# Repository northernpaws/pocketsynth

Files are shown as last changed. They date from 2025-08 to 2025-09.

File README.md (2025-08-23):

# Pocket Synth

[Online Board & Schematic View](https://kicanvas.org/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)

This repository contains my project for an STM32H7-based sequencer, synthesizer, and sampler, all in a small phone-sized pocketable form factor. 

  * 480 MHz Arm® Cortex®-M7 32-bit Processor (`STM32H743ZIT6`)
    * Floating-point unit
    * DSP instructions
    * High-speed memory controller
    * Quad SPI interface for flash
    * High-speed USB host and device mode
    * Several SAI audio blocks
  * 2.4" 240x320 TFT IPS Display (`ER-TFT024IPS-3`)
    * Capacitive touch
  * 24 bit Audio Codec (`NAU88C22YG`)
    * DAC: 94dB SNR and -84dB THD (“A” weighted)
    * ADC: 90dB SNR and -80dB THD (“A” weighted)
    * Integrated BTL speaker driver: 1W into 8Ω
    * Integrated head-phone driver: 40mW into 16Ω
  * Optional Bluetooth Classic and BLE Audio Source (`FSC-BT6038`)
    * Wirelessly connect Bluethooth headphones and speakers
    * Supports various high-fedality audio protocols
    * Note: Audio transmitter does not support other BLE protocols, such as MIDI
  * Optional Wifi and BLE capabilities (`ESP32-C3-MINI-1`)
    * Wifi sample management and transfer
    * BLE MIDI
  * Interal speaker
  * Internal microphone
  * SDRAM for sample pool and audio processing
    * Part allocated to in-memory sample pool for project
    * Part allocated to audio effects processing
    * Variable sizes in similar footprint available, up to 512Mbit:
        * 16bit * 48000Hz = 768,000b/s = 0.768Mb/s
        * 128Mb / 0.768Mb/s = 166.66 seconds of mono audio (`IS42S16800J-7TL`)
        * 256Mb / 0.768Mb/s = 333.33 seconds of mono audio (`IS42S16160J-7TLI`)
        * 512Mb / 0.768Mb/s = 666.66 seconds of mono audio (`IS42S16320F-7TLI`)
  * Micro SD Card
    * Saving and loading projects
      * Transfer and back up projects to a computer
    * Saving and loading samples
      * Load samples from a computer
      * Save samples recorded on the device
  * 3.3v NOR Flash (`MT25QUxxxxxx1xW7` 256M/128M/64M)
    * Stores device settings
    * Small storage space for projects and samples without SD card
    * Provides storage for cross-SD card samples
  * USB-C
    * USB-PD fast charging
    * Possible future audio interface mode
  * MIDI in/out via TRS minijack
  * 16 Multi-Purpose primary keys
    * Hot-swappable Kalih Choc keyswitches (V1 and V2 compatible)
    * RGB LEDs for state indicators
  * Accelerometer and Gyroscope (`LSM6DS3`)
    * Can be used as sequencer parameters
    * Can be recorded for automation inputs
    * Used for auto sleep/wake
  * USB-PD Battery Charge Controller (`MAX77789` or `MAX77757`)
    * 3A fast-charge current
    * 13.4V input voltage
    * Detection for legacy SDP, DCP, and CDP chargers
  * Two-Button Smart Reset (`STM6510`)
    * Hold two input buttons to power off the device if it freezes and power gets latched on

## Step Sequencer

The step sequencer on the device is modeled after popular semantics used by hardware sequencers, such as the Elektron Digitone and Digitakt, OP-1, OP-Z, Pocket Operators, Woovebox, etc.

> The hard requirements of the step sequencer and audio engine are not defined yet because they are under active development.

  * As many projects as the SD card or internal memory can store
    * 128 Patterns (TBD)
      * 8-16 Audio or MIDI tracks per pattern (TBD)
    * 8-24 Songs (arrangements of patterns) (TBD)
  * 8-16 voice polyphony (TBD)
    * 2-3 LFO per voice (TBD)

## Audio

The primary audio engine chain runs at 16bit 44.1Khz, but supports stereo audio effects. 16 bit audio was selected as it had suitable depth without being too large for a small embedded device to reasonably process. 44.1Khz also has a good frequency range, and has been the standard for CDs and many music streaming platforms for a long time.

### Sampling

The sampling engine runs 16bit 44.1Khz and saves and loads samples in single-channel mono.

Samples recoded from the internal or external mic are sampled at 24 bits into the device's SDRAM to provide a decent noise floor, and then filtered and downsampled to 16 bits for saving after they've been edited by the user.

The 16bit @ 44.1Khz sampling parameters provdes a good balance between audio quality, and reasonable utilization of the SDRAM without needing extremely large and expensive SDRAM chips:

```
16bit * 48000Hz = 768,000b/s = 0.768Mb/s
128Mb / 0.768Mb/s = 166.66 seconds of mono audio
256Mb / 0.768Mb/s = 333.33 seconds of mono audio
512Mb / 0.768Mb/s = 666.66 seconds of mono audio
```

> Note that some of the space calculated above (actual amount will be configurable) is allocated to the audio effects processing chain, i.e. for reverb and delay. 

## Attribution

### 3D Models

Majority of 3D models for PCB components are from their respective manufactures, with the exception of:

  - https://grabcad.com/library/kailh-low-profile-mechanical-keyboard-switch-1
  - https://grabcad.com/library/kailh-low-profile-keycaps-1
  - https://cad.grabcad.com/library/sk6812mini-e-led-1

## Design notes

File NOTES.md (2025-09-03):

## For next revision (0.2)

  * Remove volume + power knob to make room for 2x MIDI ports
  * make MIDI in/out ports multi-functional, supporting CV and sync signals

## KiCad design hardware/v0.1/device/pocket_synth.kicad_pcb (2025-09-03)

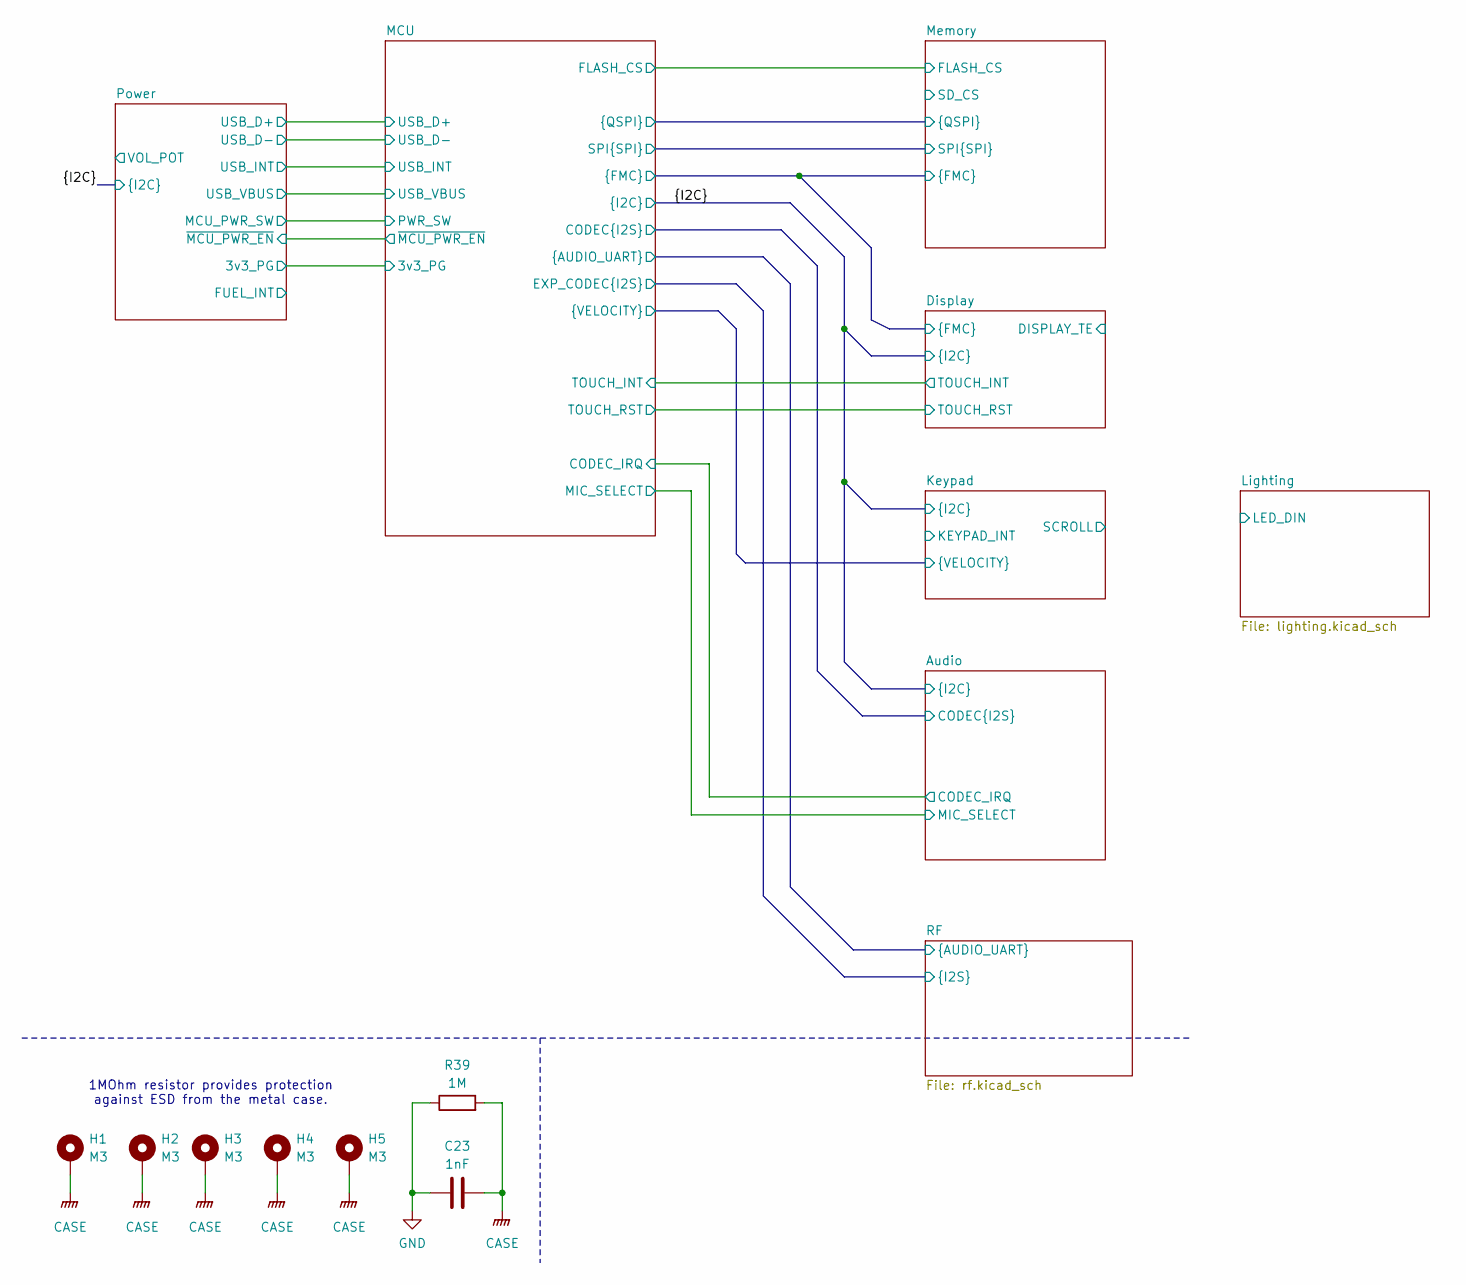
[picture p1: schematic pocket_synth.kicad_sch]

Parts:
C23: 1nF
H1, H2, H3, H4, H5: M3; MountingHole_3.2mm_M3_DIN965_Pad
R39: 1M

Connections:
CASE: C23.2, H1.1, H2.1, H3.1, H4.1, H5.1, R39.2
unnamed: C23.1, R39.1

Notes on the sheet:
1MOhm resistor provides protection against ESD from the metal case.

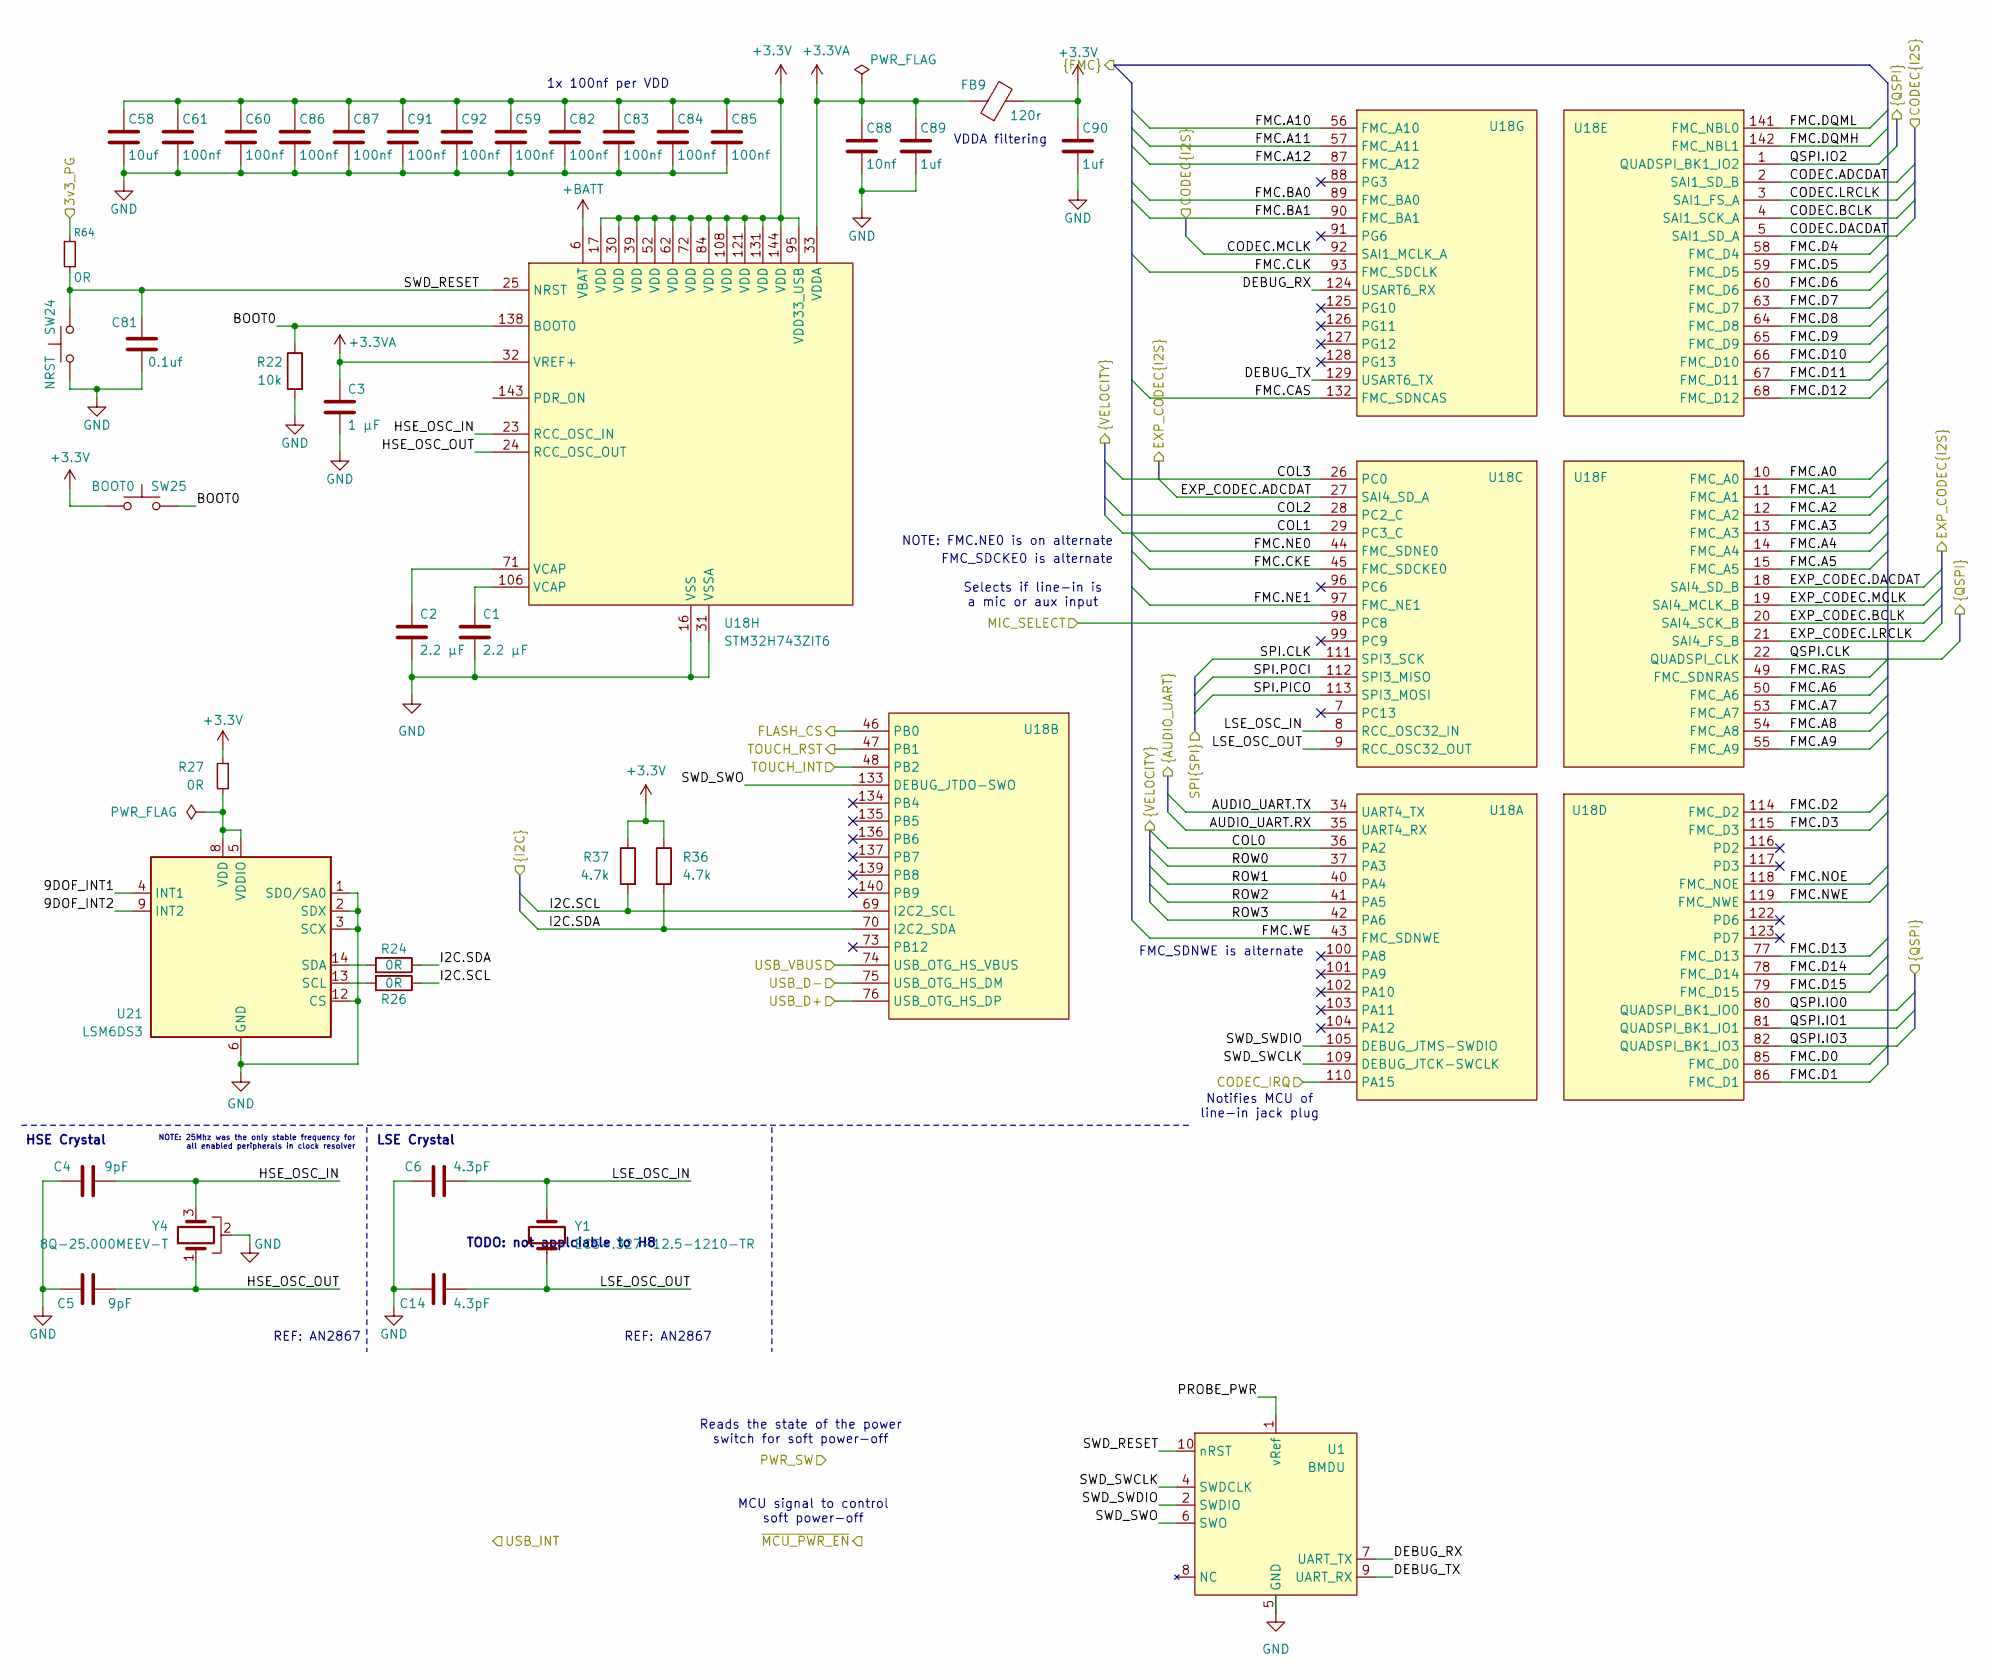
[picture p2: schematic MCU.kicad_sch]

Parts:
C1, C2: 2.2 µF; C_0402_1005Metric
C3: 1 µF; C_0402_1005Metric
C4, C5: 9pF; C_0402_1005Metric
C6, C14: 4.3pF; C_0402_1005Metric
C58: 10uf; C_0402_1005Metric
C59, C60, C61, C82, C83, C84, C85, C86, C87, C91, C92: 100nf; C_0402_1005Metric
C81: 0.1uf; C_0402_1005Metric
C88: 10nf; C_0402_1005Metric
C89, C90: 1uf; C_0402_1005Metric
FB9: 120r; L_0603_1608Metric
R22: 10k; R_0402_1005Metric
R24, R26, R27, R64: 0R; R_0402_1005Metric
R36, R37: 4.7k; R_0402_1005Metric
SW24: NRST; SW_SPST_B3U-1000P
SW25: BOOT0; SW_SPST_B3U-1000P
U1: BMDU; SAMTEC_FTSH-105-01-F-D-K
U18: STM32H743ZIT6; LQFP-144_20x20mm_P0.5mm; JLC C114408
U21: LSM6DS3; LGA-14_3x2.5mm_P0.5mm_LayoutBorder3x4y
Y1: ECS-.327-12.5-1210-TR; XTAL_ECS-.327-12.5-1210-TR; JLC C435179
Y4: 8Q-25.000MEEV-T; XTAL_8Q-25.000MEEV-T

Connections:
+3.3V: C58.1, C59.1, C60.1, C61.1, C82.1, C83.1, C84.1, C85.1, C86.1, C87.1, C90.1, C91.1, C92.1, FB9.2, R27.1, R36.1, R37.1, SW25.1, U18.17 (VDD), U18.30 (VDD), U18.39 (VDD), U18.52 (VDD), U18.62 (VDD), U18.72 (VDD), U18.84 (VDD), U18.95 (VDD33_USB), U18.108 (VDD), U18.121 (VDD), U18.131 (VDD), U18.144 (VDD); also elsewhere on the board
+3.3VA: C3.1, C88.1, C89.1, FB9.1, U18.32 (VREF+), U18.33 (VDDA)
+BATT: U18.6 (VBAT); also elsewhere on the board
/Audio/CODEC.ADCDAT: U18.2 (SAI1_SD_B); also elsewhere on the board
/Audio/CODEC.BCLK: U18.4 (SAI1_SCK_A); also elsewhere on the board
/Audio/CODEC.DACDAT: U18.5 (SAI1_SD_A); also elsewhere on the board
/Audio/CODEC.LRCLK: U18.3 (SAI1_FS_A); also elsewhere on the board
/Audio/CODEC.MCLK: U18.92 (SAI1_MCLK_A); also elsewhere on the board
/Audio/CODEC_IRQ: U18.110 (PA15); also elsewhere on the board
/Audio/MIC_SELECT: U18.98 (PC8); also elsewhere on the board
/Display/FMC.A0: U18.10 (FMC_A0); also elsewhere on the board
/Display/FMC.A1: U18.11 (FMC_A1); also elsewhere on the board
/Display/FMC.A2: U18.12 (FMC_A2); also elsewhere on the board
/Display/FMC.A3: U18.13 (FMC_A3); also elsewhere on the board
/Display/FMC.A4: U18.14 (FMC_A4); also elsewhere on the board
/Display/FMC.A5: U18.15 (FMC_A5); also elsewhere on the board
/Display/FMC.A6: U18.50 (FMC_A6); also elsewhere on the board
/Display/FMC.A7: U18.53 (FMC_A7); also elsewhere on the board
/Display/FMC.A8: U18.54 (FMC_A8); also elsewhere on the board
/Display/FMC.A9: U18.55 (FMC_A9); also elsewhere on the board
/Display/FMC.A10: U18.56 (FMC_A10); also elsewhere on the board
/Display/FMC.A11: U18.57 (FMC_A11); also elsewhere on the board
/Display/FMC.A12: U18.87 (FMC_A12); also elsewhere on the board
/Display/FMC.BA0: U18.89 (FMC_BA0); also elsewhere on the board
/Display/FMC.BA1: U18.90 (FMC_BA1); also elsewhere on the board
/Display/FMC.CAS: U18.132 (FMC_SDNCAS); also elsewhere on the board
/Display/FMC.CKE: U18.45 (FMC_SDCKE0); also elsewhere on the board
/Display/FMC.CLK: U18.93 (FMC_SDCLK); also elsewhere on the board
/Display/FMC.D0: U18.85 (FMC_D0); also elsewhere on the board
/Display/FMC.D1: U18.86 (FMC_D1); also elsewhere on the board
/Display/FMC.D2: U18.114 (FMC_D2); also elsewhere on the board
/Display/FMC.D3: U18.115 (FMC_D3); also elsewhere on the board
/Display/FMC.D4: U18.58 (FMC_D4); also elsewhere on the board
/Display/FMC.D5: U18.59 (FMC_D5); also elsewhere on the board
/Display/FMC.D6: U18.60 (FMC_D6); also elsewhere on the board
/Display/FMC.D7: U18.63 (FMC_D7); also elsewhere on the board
/Display/FMC.D8: U18.64 (FMC_D8); also elsewhere on the board
/Display/FMC.D9: U18.65 (FMC_D9); also elsewhere on the board
/Display/FMC.D10: U18.66 (FMC_D10); also elsewhere on the board
/Display/FMC.D11: U18.67 (FMC_D11); also elsewhere on the board
/Display/FMC.D12: U18.68 (FMC_D12); also elsewhere on the board
/Display/FMC.D13: U18.77 (FMC_D13); also elsewhere on the board
/Display/FMC.D14: U18.78 (FMC_D14); also elsewhere on the board
/Display/FMC.D15: U18.79 (FMC_D15); also elsewhere on the board
/Display/FMC.DQMH: U18.142 (FMC_NBL1); also elsewhere on the board
/Display/FMC.DQML: U18.141 (FMC_NBL0); also elsewhere on the board
/Display/FMC.NE0: U18.44 (FMC_SDNE0); also elsewhere on the board
/Display/FMC.NE1: U18.97 (FMC_NE1); also elsewhere on the board
/Display/FMC.NOE: U18.118 (FMC_NOE); also elsewhere on the board
/Display/FMC.NWE: U18.119 (FMC_NWE); also elsewhere on the board
/Display/FMC.RAS: U18.49 (FMC_SDNRAS); also elsewhere on the board
/Display/FMC.WE: U18.43 (FMC_SDNWE); also elsewhere on the board
/Display/TOUCH_INT: U18.48 (PB2); also elsewhere on the board
/Display/TOUCH_RST: U18.47 (PB1); also elsewhere on the board
/I2C.SCL: R26.1, R37.2, U18.69 (I2C2_SCL); also elsewhere on the board
/I2C.SDA: R24.1, R36.2, U18.70 (I2C2_SDA); also elsewhere on the board
/Keypad/COL0: U18.36 (PA2); also elsewhere on the board
/Keypad/COL1: U18.29 (PC3_C); also elsewhere on the board
/Keypad/COL2: U18.28 (PC2_C); also elsewhere on the board
/Keypad/COL3: U18.26 (PC0); also elsewhere on the board
/Keypad/ROW0: U18.37 (PA3); also elsewhere on the board
/Keypad/ROW1: U18.40 (PA4); also elsewhere on the board
/Keypad/ROW2: U18.41 (PA5); also elsewhere on the board
/Keypad/ROW3: U18.42 (PA6); also elsewhere on the board
/MCU/9DOF_INT1: U21.4 (INT1)
/MCU/9DOF_INT2: U21.9 (INT2)
/MCU/AUDIO_UART.RX: U18.35 (UART4_RX); also elsewhere on the board
/MCU/AUDIO_UART.TX: U18.34 (UART4_TX); also elsewhere on the board
/MCU/BOOT0: R22.1, SW25.2, U18.138 (BOOT0)
/MCU/DEBUG_RX: U1.7 (UART_TX), U18.124 (USART6_RX)
/MCU/DEBUG_TX: U1.9 (UART_RX), U18.129 (USART6_TX)
/MCU/EXP_CODEC.ADCDAT: U18.27 (SAI4_SD_A); also elsewhere on the board
/MCU/EXP_CODEC.BCLK: U18.20 (SAI4_SCK_B); also elsewhere on the board
/MCU/EXP_CODEC.DACDAT: U18.18 (SAI4_SD_B); also elsewhere on the board
/MCU/EXP_CODEC.LRCLK: U18.21 (SAI4_FS_B); also elsewhere on the board
/MCU/EXP_CODEC.MCLK: U18.19 (SAI4_MCLK_B); also elsewhere on the board
/MCU/FLASH_CS: U18.46 (PB0); also elsewhere on the board
/MCU/HSE_OSC_IN: C4.2, U18.23 (RCC_OSC_IN), Y4.3
/MCU/HSE_OSC_OUT: C5.2, U18.24 (RCC_OSC_OUT), Y4.1
/MCU/LSE_OSC_IN: C6.2, U18.8 (RCC_OSC32_IN), Y1.2
/MCU/LSE_OSC_OUT: C14.2, U18.9 (RCC_OSC32_OUT), Y1.1
/MCU/PROBE_PWR: U1.1 (vRef)
/MCU/QSPI.CLK: U18.22 (QUADSPI_CLK); also elsewhere on the board
/MCU/QSPI.IO0: U18.80 (QUADSPI_BK1_IO0); also elsewhere on the board
/MCU/QSPI.IO1: U18.81 (QUADSPI_BK1_IO1); also elsewhere on the board
/MCU/QSPI.IO2: U18.1 (QUADSPI_BK1_IO2); also elsewhere on the board
/MCU/QSPI.IO3: U18.82 (QUADSPI_BK1_IO3); also elsewhere on the board
/MCU/SPI.CLK: U18.111 (SPI3_SCK); also elsewhere on the board
/MCU/SPI.PICO: U18.113 (SPI3_MOSI); also elsewhere on the board
/MCU/SPI.POCI: U18.112 (SPI3_MISO); also elsewhere on the board
/MCU/SWD_RESET: C81.2, R64.2, SW24.2, U1.10 (nRST), U18.25 (NRST)
/MCU/SWD_SWCLK: U1.4 (SWDCLK), U18.109 (DEBUG_JTCK-SWCLK)
/MCU/SWD_SWDIO: U1.2 (SWDIO), U18.105 (DEBUG_JTMS-SWDIO)
/MCU/SWD_SWO: U1.6 (SWO), U18.133 (DEBUG_JTDO-SWO)
/MCU/USB_VBUS: U18.74 (USB_OTG_HS_VBUS)
/Power/3v3_PG: R64.1; also elsewhere on the board
/Power/USB_D+: U18.76 (USB_OTG_HS_DP); also elsewhere on the board
/Power/USB_D-: U18.75 (USB_OTG_HS_DM); also elsewhere on the board
GND: C1.2, C2.2, C3.2, C4.1, C5.1, C6.1, C14.1, C58.2, C59.2, C60.2, C61.2, C81.1, C82.2, C83.2, C84.2, C85.2, C86.2, C87.2, C88.2, C89.2, C90.2, C91.2, C92.2, R22.2, SW24.1, U1.3 (GND), U1.5 (GND), U18.16 (VSS), U18.31 (VSSA), U18.38 (VSS), U18.51 (VSS), U18.61 (VSS), U18.83 (VSS), U18.94 (VSS), U18.107 (VSS), U18.120 (VSS), U18.130 (VSS), U21.1 (SDO/SA0), U21.2 (SDX), U21.3 (SCX), U21.6 (GND), U21.7 (GND), U21.12 (CS), Y4.2; also elsewhere on the board
unnamed: C1.1, U18.106 (VCAP)
unnamed: C2.1, U18.71 (VCAP)
unnamed: R26.2, U21.13 (SCL)
unnamed: R24.2, U21.14 (SDA)
unnamed: R27.2, U21.5 (VDDIO), U21.8 (VDD)

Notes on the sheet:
MCU signal to control soft power-off
HSE Crystal
NOTE: 25Mhz was the only stable frequency for all enabled peripherals in clock resolver
FMC_SDCKE0 is alternate
Selects if line-in is a mic or aux input
1x 100nf per VDD
TODO: not applciable to H8
VDDA filtering
REF: AN2867
FMC_SDNWE is alternate
Notifies MCU of line-in jack plug
NOTE: FMC.NE0 is on alternate
Reads the state of the power switch for soft power-off
LSE Crystal

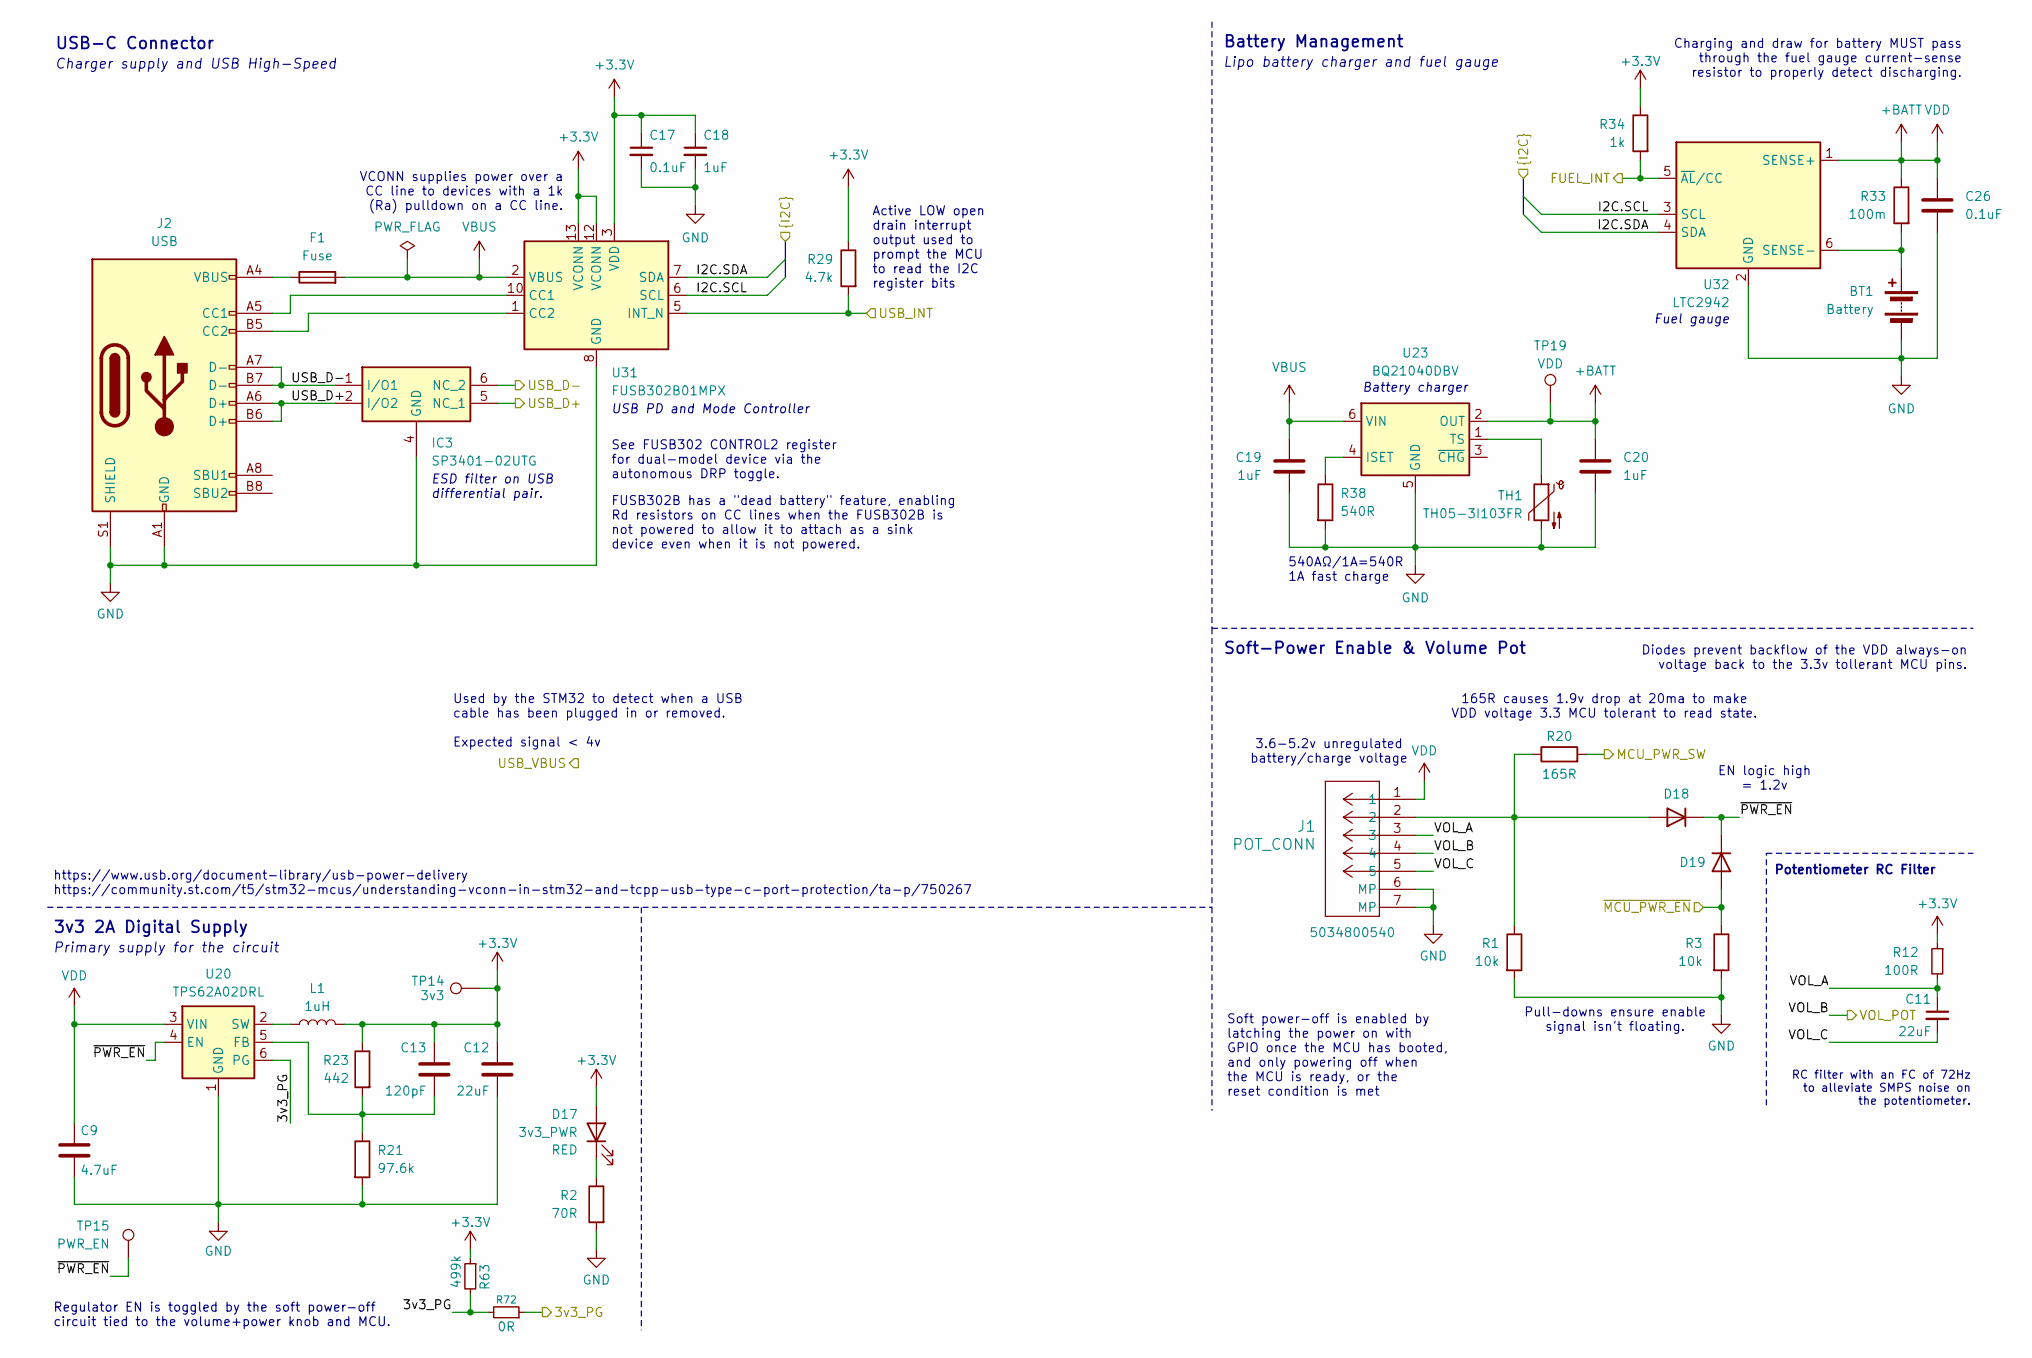
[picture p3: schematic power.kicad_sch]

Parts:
BT1: Battery; JST_PH_S2B-PH-SM4-TB_1x02-1MP_P2.00mm_Horizontal
C9: 4.7uF; C_0805_2012Metric
C11: 22uF; C_0402_1005Metric
C12: 22uF; C_0805_2012Metric
C13: 120pF; C_0805_2012Metric
C17: 0.1uF; C_0402_1005Metric
C18: 1uF; C_0402_1005Metric
C19, C20: 1uF; C_0805_2012Metric
C26: 0.1uF; C_0603_1608Metric
D17: 3v3_PWR; LED_0805_2012Metric_Pad1.15x1.40mm_HandSolder
D18, D19: D; D_0603_1608Metric
F1: Fuse; Fuse_0805_2012Metric
IC3: SP3401-02UTG; SP340102UTG; Mouser Part Number 576-SP3401-02UTG
J1: POT_CONN; CONN_503480-0540_MOL; JLC C5527934
J2: USB; USB_C_Receptacle_G-Switch_GT-USB-7010ASV; JLC C2988369
L1: 1uH; L_1008_2520Metric; JLC C435392
R1: 10k
R2: 70R; C_0402_1005Metric
R3: 10k; R_0402_1005Metric
R12: 100R; C_0402_1005Metric
R20: 165R; C_0402_1005Metric
R21: 97.6k; R_0603_1608Metric
R23: 442; R_0603_1608Metric
R29: 4.7k; C_0402_1005Metric
R33: 100m; C_0402_1005Metric
R34: 1k; R_0402_1005Metric
R38: 540R; R_0402_1005Metric
R63: 499k; C_0402_1005Metric
R72: 0R; C_0402_1005Metric
TH1: TH05-3I103FR; R_0402_1005Metric_Pad0.72x0.64mm_HandSolder
TP14: 3v3; TestPoint_Pad_D1.0mm
TP15: PWR_EN; TestPoint_Pad_D1.0mm
TP19: VDD; TestPoint_Pad_D1.0mm
U20: TPS62A02DRL; SOT-563; JLC C5350187
U23: BQ21040DBV; SOT-23-6; JLC C78978
U31: FUSB302B01MPX; WQFN-14-1EP_2.5x2.5mm_P0.5mm_EP1.45x1.45mm; JLC C488155
U32: LTC2942; DFN-6-1EP_3x2mm_P0.5mm_EP1.65x1.35mm; JLC C683656

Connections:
+3.3V: C12.1, C13.1, C17.1, C18.1, D17.2 (A), L1.2, R12.1, R23.1, R29.1, R34.1, R63.1, TP14.1, U31.3 (VDD), U31.4 (VDD), U31.12 (VCONN), U31.13 (VCONN); also elsewhere on the board
+BATT: C9.1, C20.1, C26.1, J1.1, R33.1, TP19.1, U20.3 (VIN), U23.2 (OUT), U32.1 (SENSE+); also elsewhere on the board
/I2C.SCL: U31.6 (SCL), U32.3 (SCL); also elsewhere on the board
/I2C.SDA: U31.7 (SDA), U32.4 (SDA); also elsewhere on the board
/MCU/PWR_SW: R20.2
/MCU/USB_INT: R29.2, U31.5 (INT_N)
/MCU/~MCU_PWR_EN: D19.2 (A), R3.1
/Power/3v3_PG: R63.2, R72.1, R72.2, U20.6 (PG); also elsewhere on the board
/Power/FUEL_INT: R34.2, U32.5 (~AL/CC)
/Power/USB_D+: IC3.2 (I/O2), IC3.5 (NC_1), J2.A6 (D+), J2.B6 (D+); also elsewhere on the board
/Power/USB_D-: IC3.1 (I/O1), IC3.6 (NC_2), J2.A7 (D-), J2.B7 (D-); also elsewhere on the board
/Power/VOL_A: C11.1, J1.3, R12.2
/Power/VOL_B: J1.4
/Power/VOL_C: C11.2, J1.5
/Power/~PWR_EN: D18.1 (K), D19.1 (K), TP15.1, U20.4 (EN)
GND: BT1.2 (-), C9.2, C12.2, C17.2, C18.2, C19.2, C20.2, C26.2, IC3.3 (GND), IC3.4 (GND), J1.6 (MP), J1.7 (MP), J2.A1 (GND), J2.A12 (GND), J2.B1 (GND), J2.B12 (GND), J2.S1 (SHIELD), R1.2, R2.2, R3.2, R21.2, R38.2, TH1.2, U20.1 (GND), U23.5 (GND), U31.8 (GND), U31.9 (GND), U31.15 (GND), U32.2 (GND); also elsewhere on the board
unnamed: BT1.1 (+), R33.2, U32.6 (SENSE-)
unnamed: D17.1 (K), R2.1
unnamed: D18.2 (A), J1.2, R1.1, R20.1
unnamed: F1.1, J2.A4 (VBUS), J2.A9 (VBUS), J2.B4 (VBUS), J2.B9 (VBUS)
unnamed: J2.A5 (CC1), U31.10 (CC1), U31.11 (CC1)
unnamed: J2.B5 (CC2), U31.1 (CC2), U31.14 (CC2)
unnamed: C13.2, R21.1, R23.2, U20.5 (FB)
unnamed: L1.1, U20.2 (SW)
unnamed: R38.1, U23.4 (ISET)
unnamed: TH1.1, U23.1 (TS)
VBUS: C19.1, F1.2, U23.6 (VIN), U31.2 (VBUS)

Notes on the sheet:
Lipo battery charger and fuel gauge
See FUSB302 CONTROL2 register for dual-model device via the autonomous DRP toggle.
Charging and draw for battery MUST pass through the fuel gauge current-sense resistor to properly detect discharging.
Battery charger
165R causes 1.9v drop at 20ma to make VDD voltage 3.3 MCU tolerant to read state.
Primary supply for the circuit
Regulator EN is toggled by the soft power-off circuit tied to the volume+power knob and MCU.
Used by the STM32 to detect when a USB cable has been plugged in or removed. Expected signal < 4v
3.6-5.2v unregulated battery/charge voltage
RC filter with an FC of 72Hz to alleviate SMPS noise on the potentiometer.
Battery Management
Fuel gauge
Soft-Power Enable & Volume Pot
Charger supply and USB High-Speed
USB-C Connector
540AΩ/1A=540R 1A fast charge
FUSB302B has a "dead battery" feature, enabling Rd resistors on CC lines when the FUSB302B is not powered to allow it to attach as a sink device even when it is not powered.
EN logic high = 1.2v
Pull-downs ensure enable signal isn't floating.
Active LOW open drain interrupt output used to prompt the MCU to read the I2C register bits
ESD filter on USB differential pair.
USB PD and Mode Controller
Diodes prevent backflow of the VDD always-on voltage back to the 3.3v tollerant MCU pins.
3v3 2A Digital Supply
Potentiometer RC Filter
https://www.usb.org/document-library/usb-power-delivery https://community.st.com/t5/stm32-mcus/understanding-vconn-in-stm32-and-tcpp-usb-type-c-port-protection/ta-p/750267
VCONN supplies power over a CC line to devices with a 1k (Ra) pulldown on a CC line.
Soft power-off is enabled by latching the power on with GPIO once the MCU has booted, and only powering off when the MCU is ready, or the reset condition is met

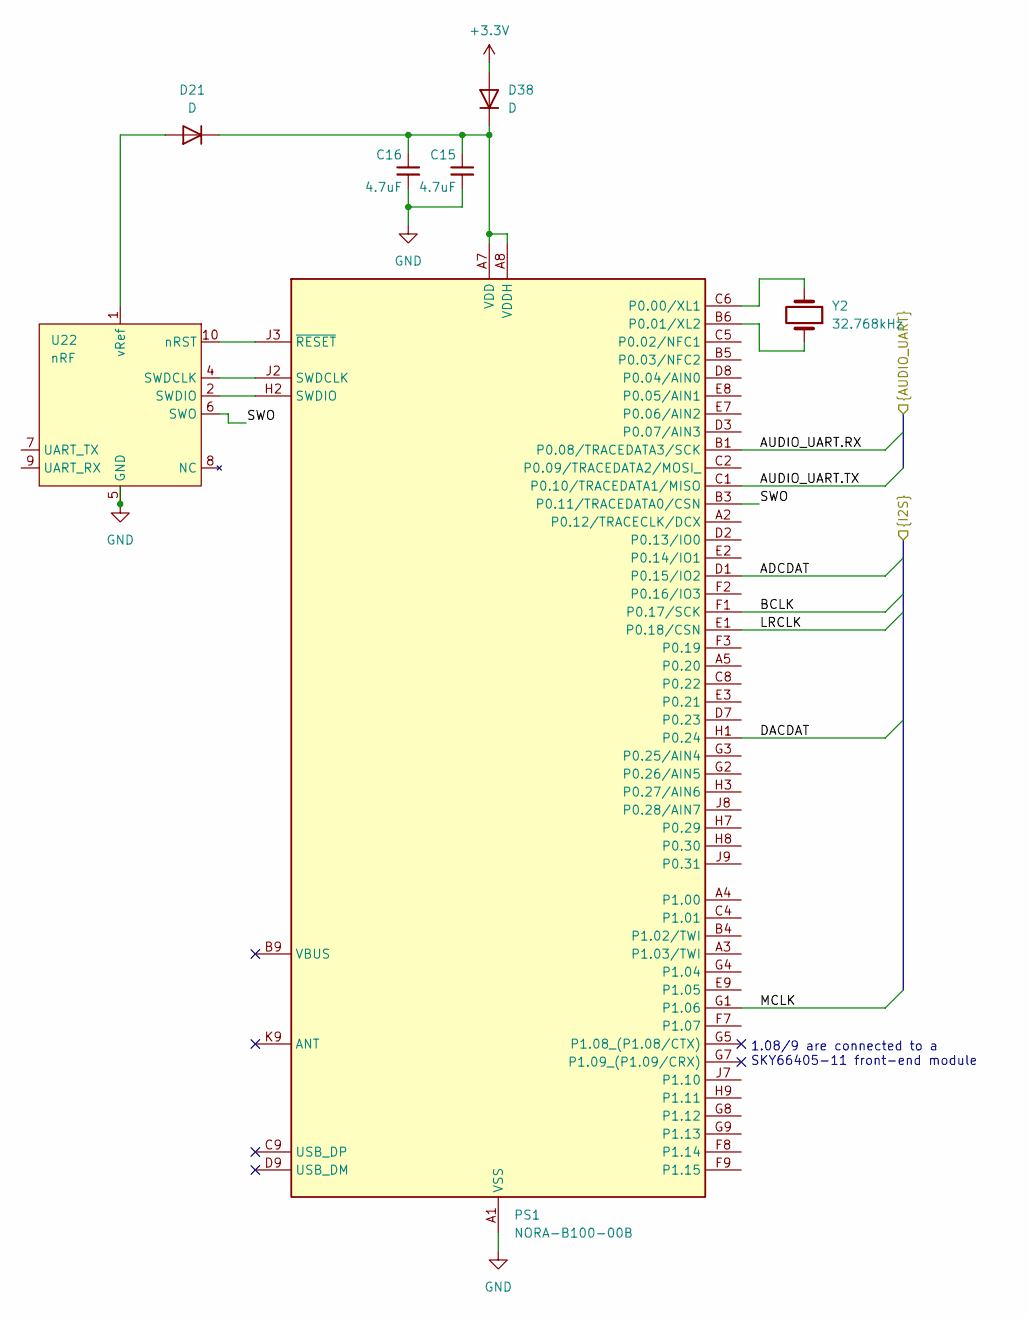
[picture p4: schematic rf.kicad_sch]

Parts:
C15, C16: 4.7uF; C_0402_1005Metric
D21, D38: D; D_0402_1005Metric
PS1: NORA-B100-00B; NORAB10000B; Mouser Part Number 377-NORA-B100-00B
U22: nRF; SAMTEC_FTSH-105-01-F-D-K
Y2: 32.768kHz

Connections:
+3.3V: D38.2 (A); also elsewhere on the board
/MCU/AUDIO_UART.RX: PS1.B1 (P0.08/TRACEDATA3/SCK); also elsewhere on the board
/MCU/AUDIO_UART.TX: PS1.C1 (P0.10/TRACEDATA1/MISO); also elsewhere on the board
/MCU/EXP_CODEC.ADCDAT: PS1.D1 (P0.15/IO2); also elsewhere on the board
/MCU/EXP_CODEC.BCLK: PS1.F1 (P0.17/SCK); also elsewhere on the board
/MCU/EXP_CODEC.DACDAT: PS1.H1 (P0.24); also elsewhere on the board
/MCU/EXP_CODEC.LRCLK: PS1.E1 (P0.18/CSN); also elsewhere on the board
/MCU/EXP_CODEC.MCLK: PS1.G1 (P1.06); also elsewhere on the board
/RF/SWO: PS1.B3 (P0.11/TRACEDATA0/CSN), U22.6 (SWO)
GND: C15.2, C16.2, PS1.A1 (VSS), PS1.A9 (VSS_2), PS1.B2 (VSS_3), PS1.B8 (VSS_4), PS1.E4 (VSS_5), PS1.E5 (VSS_6), PS1.F4 (VSS_7), PS1.F5 (VSS_8), PS1.K2 (VSS_9), PS1.K3 (VSS_10), PS1.K5 (VSS_11), PS1.K7 (VSS_12), PS1.K8 (VSS_13), PS1.L1 (VSS_14), PS1.L9 (VSS_15), PS1.M1 (VSS_16), PS1.M2 (VSS_17), PS1.M8 (VSS_18), PS1.M9 (VSS_19), U22.3 (GND), U22.5 (GND); also elsewhere on the board
unnamed: D21.2 (A), U22.1 (vRef)
unnamed: C15.1, C16.1, D21.1 (K), D38.1 (K), PS1.A7 (VDD), PS1.A8 (VDDH), PS1.B7 (VDD_2)
unnamed: PS1.C6 (P0.00/XL1), Y2.2
unnamed: PS1.B6 (P0.01/XL2), Y2.1
unnamed: PS1.J2 (SWDCLK), U22.4 (SWDCLK)
unnamed: PS1.H2 (SWDIO), U22.2 (SWDIO)
unnamed: PS1.J3 (~RESET), U22.10 (nRST)

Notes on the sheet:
1.08/9 are connected to a SKY66405-11 front-end module

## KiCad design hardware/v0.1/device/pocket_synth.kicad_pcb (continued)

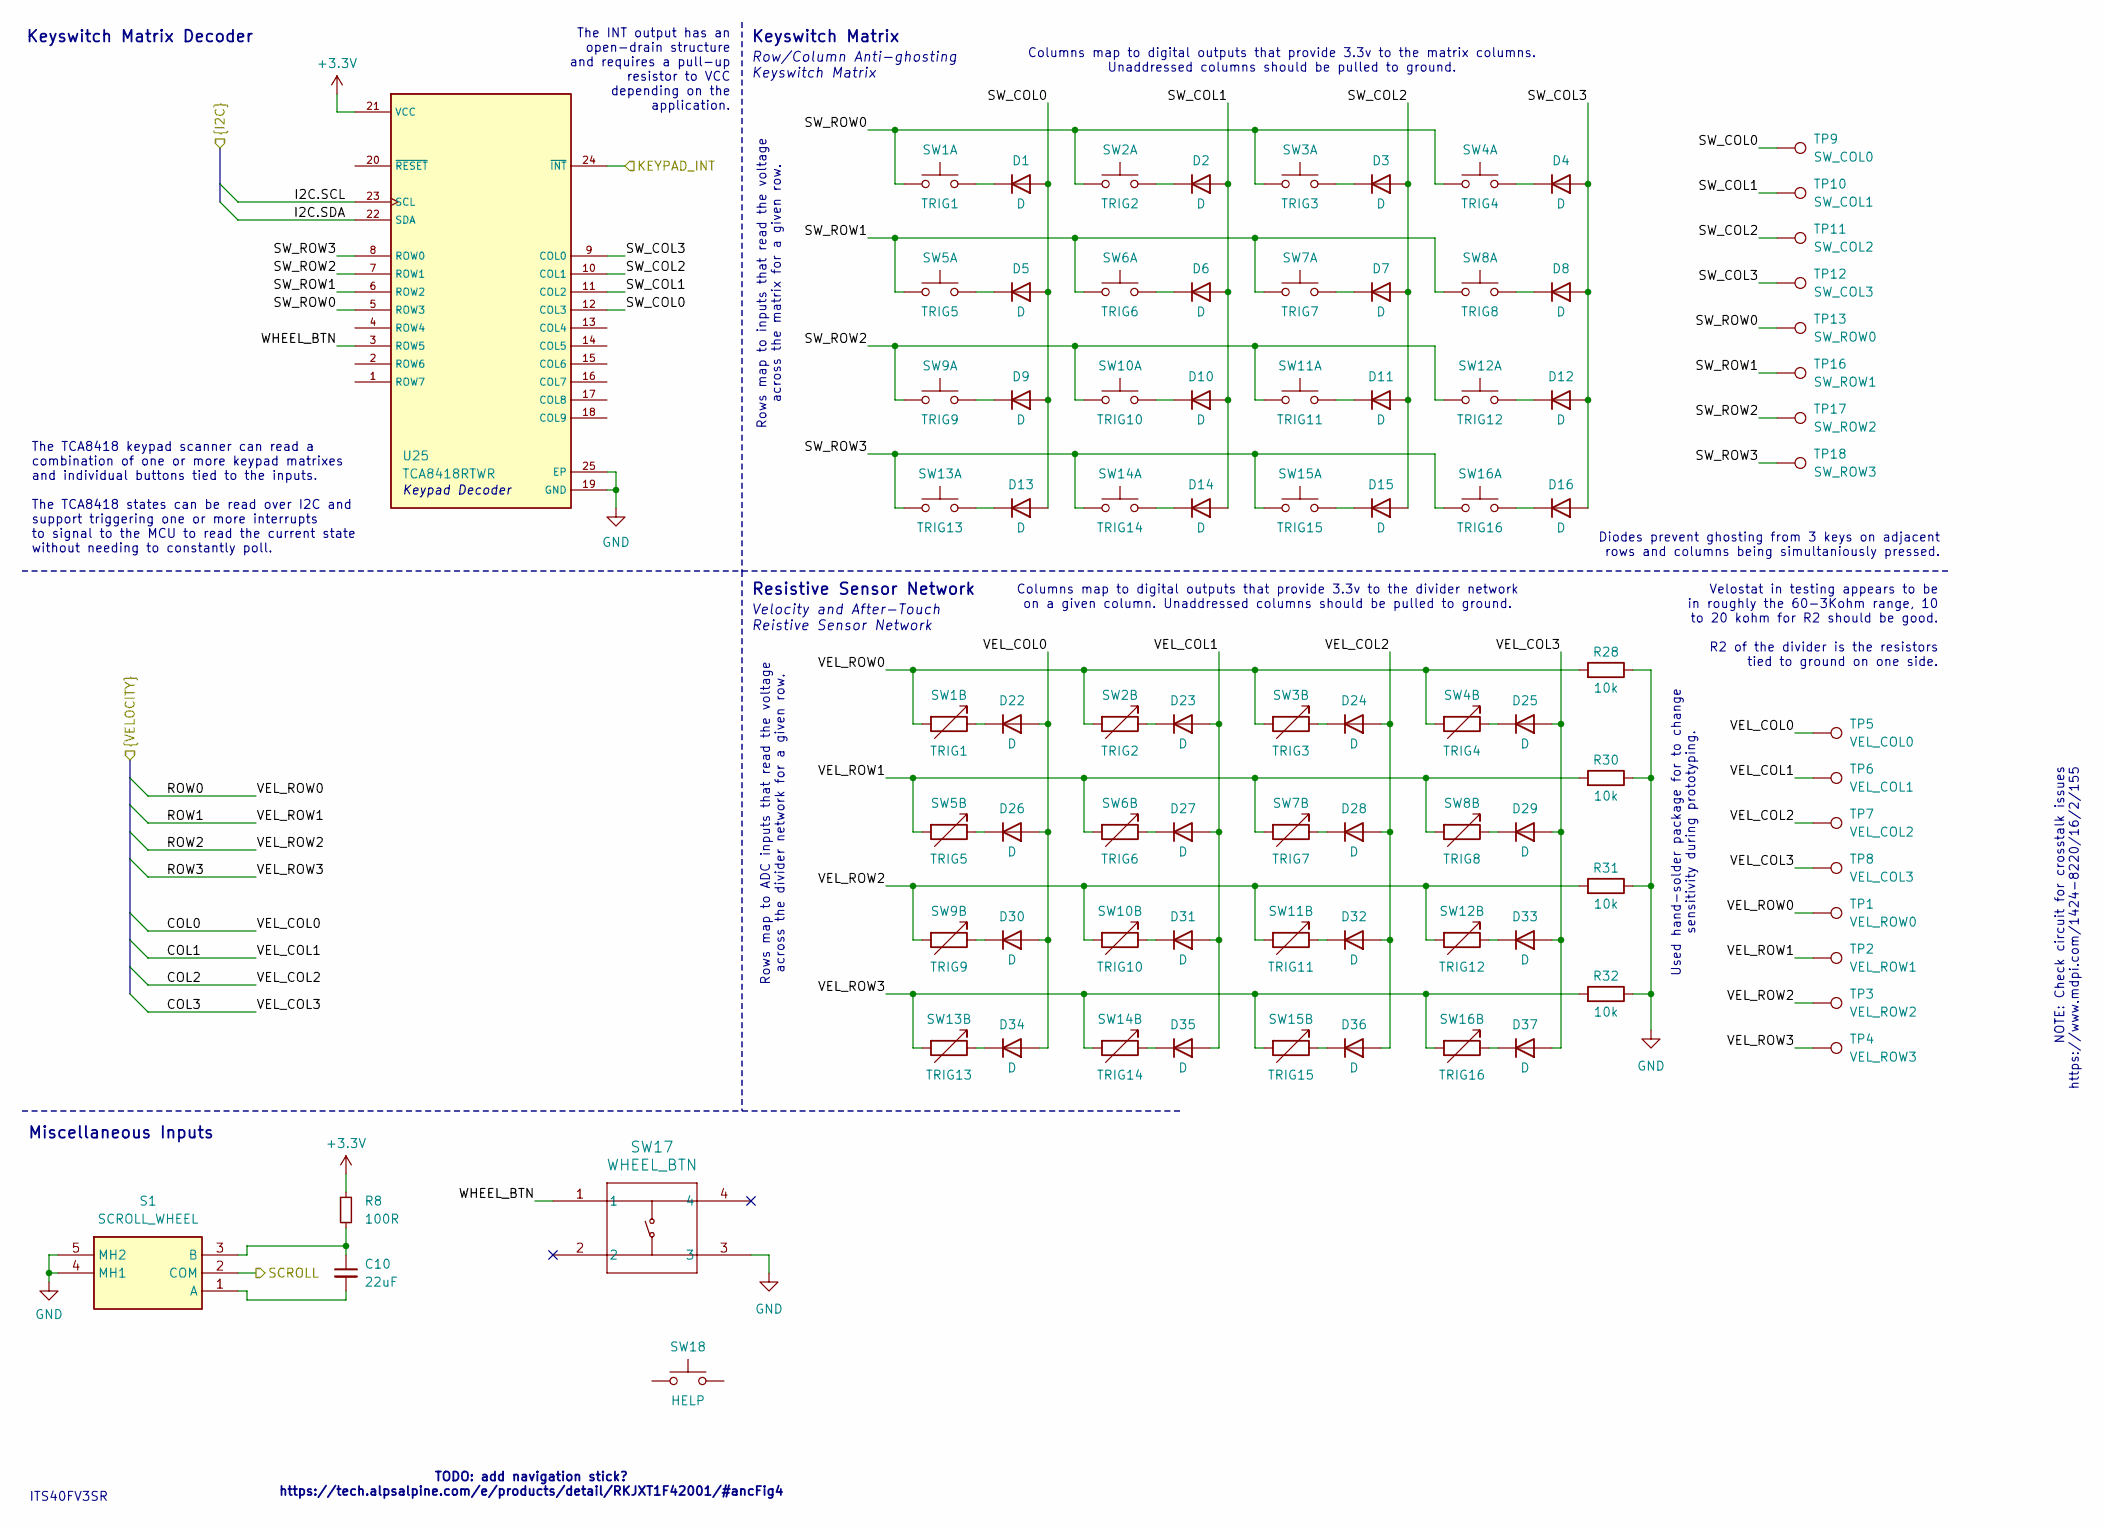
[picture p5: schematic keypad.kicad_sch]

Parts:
C10: 22uF; C_0402_1005Metric
D1, D2, D3, D4, D5, D6, D7, D8, D9, D10, D11, D12, D13, D14, D15, D16, D22, D23, D24, D25, D26, D27, D28, D29, D30, D31, D32, D33, D34, D35, D36, D37: D; D_0402_1005Metric
R8: 100R; R_0402_1005Metric
R28, R30, R31, R32: 10k; R_0805_2012Metric_Pad1.20x1.40mm_HandSolder
S1: SCROLL_WHEEL; 2416191-1; Manufacturer_Part_Number 2416191-1; Mouser Part Number 655-2416191-1
SW1: TRIG1; SW_Hotswap_Kailh_Choc_V1_1.00u_Pressure
SW2: TRIG2; SW_Hotswap_Kailh_Choc_V1_1.00u_Pressure
SW3: TRIG3; SW_Hotswap_Kailh_Choc_V1_1.00u_Pressure
SW4: TRIG4; SW_Hotswap_Kailh_Choc_V1_1.00u_Pressure
SW5: TRIG5; SW_Hotswap_Kailh_Choc_V1_1.00u_Pressure
SW6: TRIG6; SW_Hotswap_Kailh_Choc_V1_1.00u_Pressure
SW7: TRIG7; SW_Hotswap_Kailh_Choc_V1_1.00u_Pressure
SW8: TRIG8; SW_Hotswap_Kailh_Choc_V1_1.00u_Pressure
SW9: TRIG9; SW_Hotswap_Kailh_Choc_V1_1.00u_Pressure
SW10: TRIG10; SW_Hotswap_Kailh_Choc_V1_1.00u_Pressure
SW11: TRIG11; SW_Hotswap_Kailh_Choc_V1_1.00u_Pressure
SW12: TRIG12; SW_Hotswap_Kailh_Choc_V1_1.00u_Pressure
SW13: TRIG13; SW_Hotswap_Kailh_Choc_V1_1.00u_Pressure
SW14: TRIG14; SW_Hotswap_Kailh_Choc_V1_1.00u_Pressure
SW15: TRIG15; SW_Hotswap_Kailh_Choc_V1_1.00u_Pressure
SW16: TRIG16; SW_Hotswap_Kailh_Choc_V1_1.00u_Pressure
SW17: WHEEL_BTN; KMR221_CNK
SW18: HELP; SW_SPST_EVQQ2
TP1: VEL_ROW0; TestPoint_Pad_D1.0mm
TP2: VEL_ROW1; TestPoint_Pad_D1.0mm
TP3: VEL_ROW2; TestPoint_Pad_D1.0mm
TP4: VEL_ROW3; TestPoint_Pad_D1.0mm
TP5: VEL_COL0; TestPoint_Pad_D1.0mm
TP6: VEL_COL1; TestPoint_Pad_D1.0mm
TP7: VEL_COL2; TestPoint_Pad_D1.0mm
TP8: VEL_COL3; TestPoint_Pad_D1.0mm
TP9: SW_COL0; TestPoint_Pad_D1.0mm
TP10: SW_COL1; TestPoint_Pad_D1.0mm
TP11: SW_COL2; TestPoint_Pad_D1.0mm
TP12: SW_COL3; TestPoint_Pad_D1.0mm
TP13: SW_ROW0; TestPoint_Pad_D1.0mm
TP16: SW_ROW1; TestPoint_Pad_D1.0mm
TP17: SW_ROW2; TestPoint_Pad_D1.0mm
TP18: SW_ROW3; TestPoint_Pad_D1.0mm
U25: TCA8418RTWR; WQFN-24-1EP_4x4mm_P0.5mm_EP2.45x2.45mm; JLC C138713

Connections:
+3.3V: R8.1, U25.21 (VCC); also elsewhere on the board
/I2C.SCL: U25.23 (SCL); also elsewhere on the board
/I2C.SDA: U25.22 (SDA); also elsewhere on the board
/Keypad/COL0: D22.2 (A), D26.2 (A), D30.2 (A), D34.2 (A), TP5.1; also elsewhere on the board
/Keypad/COL1: D23.2 (A), D27.2 (A), D31.2 (A), D35.2 (A), TP6.1; also elsewhere on the board
/Keypad/COL2: D24.2 (A), D28.2 (A), D32.2 (A), D36.2 (A), TP7.1; also elsewhere on the board
/Keypad/COL3: D25.2 (A), D29.2 (A), D33.2 (A), D37.2 (A), TP8.1; also elsewhere on the board
/Keypad/KEYPAD_INT: U25.24 (~INT)
/Keypad/ROW0: R28.2, SW1.3, SW2.3, SW3.3, SW4.3, TP1.1; also elsewhere on the board
/Keypad/ROW1: R30.2, SW5.3, SW6.3, SW7.3, SW8.3, TP2.1; also elsewhere on the board
/Keypad/ROW2: R31.2, SW9.3, SW10.3, SW11.3, SW12.3, TP3.1; also elsewhere on the board
/Keypad/ROW3: R32.2, SW13.3, SW14.3, SW15.3, SW16.3, TP4.1; also elsewhere on the board
/Keypad/SCROLL: S1.2 (COM)
/Keypad/SW_COL0: D1.2 (A), D5.2 (A), D9.2 (A), D13.2 (A), TP9.1, U25.12 (COL3)
/Keypad/SW_COL1: D2.2 (A), D6.2 (A), D10.2 (A), D14.2 (A), TP10.1, U25.11 (COL2)
/Keypad/SW_COL2: D3.2 (A), D7.2 (A), D11.2 (A), D15.2 (A), TP11.1, U25.10 (COL1)
/Keypad/SW_COL3: D4.2 (A), D8.2 (A), D12.2 (A), D16.2 (A), TP12.1, U25.9 (COL0)
/Keypad/SW_ROW0: SW1.1, SW2.1, SW3.1, SW4.1, TP13.1, U25.5 (ROW3)
/Keypad/SW_ROW1: SW5.1, SW6.1, SW7.1, SW8.1, TP16.1, U25.6 (ROW2)
/Keypad/SW_ROW2: SW9.1, SW10.1, SW11.1, SW12.1, TP17.1, U25.7 (ROW1)
/Keypad/SW_ROW3: SW13.1, SW14.1, SW15.1, SW16.1, TP18.1, U25.8 (ROW0)
/Keypad/WHEEL_BTN: SW17.1, U25.3 (ROW5)
GND: R28.1, R30.1, R31.1, R32.1, S1.4 (MH1), S1.5 (MH2), SW17.3, U25.19 (GND), U25.25 (EP); also elsewhere on the board
unnamed: D1.1 (K), SW1.2
unnamed: D2.1 (K), SW2.2
unnamed: D3.1 (K), SW3.2
unnamed: D4.1 (K), SW4.2
unnamed: D5.1 (K), SW5.2
unnamed: D6.1 (K), SW6.2
unnamed: D7.1 (K), SW7.2
unnamed: D8.1 (K), SW8.2
unnamed: D9.1 (K), SW9.2
unnamed: D10.1 (K), SW10.2
unnamed: D11.1 (K), SW11.2
unnamed: D12.1 (K), SW12.2
unnamed: D13.1 (K), SW13.2
unnamed: D14.1 (K), SW14.2
unnamed: D15.1 (K), SW15.2
unnamed: D16.1 (K), SW16.2
unnamed: D22.1 (K), SW1.4
unnamed: D23.1 (K), SW2.4
unnamed: D24.1 (K), SW3.4
unnamed: D25.1 (K), SW4.4
unnamed: D26.1 (K), SW5.4
unnamed: D27.1 (K), SW6.4
unnamed: D28.1 (K), SW7.4
unnamed: D29.1 (K), SW8.4
unnamed: D30.1 (K), SW9.4
unnamed: D31.1 (K), SW10.4
unnamed: D32.1 (K), SW11.4
unnamed: D33.1 (K), SW12.4
unnamed: D34.1 (K), SW13.4
unnamed: D35.1 (K), SW14.4
unnamed: D36.1 (K), SW15.4
unnamed: D37.1 (K), SW16.4
unnamed: C10.2, S1.1 (A)
unnamed: C10.1, R8.2, S1.3 (B)

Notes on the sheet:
Rows map to ADC inputs that read the voltage across the divider network for a given row.
Miscellaneous Inputs
NOTE: Check circuit for crosstalk issues https://www.mdpi.com/1424-8220/16/2/155
The INT output has an open-drain structure and requires a pull-up resistor to VCC depending on the application.
Row/Column Anti-ghosting Keyswitch Matrix
The TCA8418 keypad scanner can read a combination of one or more keypad matrixes and individual buttons tied to the inputs. The TCA8418 states can be read over I2C and support triggering one or more interrupts to signal to the MCU to read the current state without needing to constantly poll.
Velocity and After-Touch Reistive Sensor Network
Velostat in testing appears to be in roughly the 60-3Kohm range, 10 to 20 kohm for R2 should be good. R2 of the divider is the resistors tied to ground on one side.
ITS40FV3SR
Keyswitch Matrix
Keypad Decoder
Keyswitch Matrix Decoder
TODO: add navigation stick? https://tech.alpsalpine.com/e/products/detail/RKJXT1F42001/#ancFig4
Rows map to inputs that read the voltage across the matrix for a given row.
Used hand-solder package for to change sensitivity during prototyping.
Columns map to digital outputs that provide 3.3v to the matrix columns. Unaddressed columns should be pulled to ground.
Diodes prevent ghosting from 3 keys on adjacent rows and columns being simultaniously pressed.
Columns map to digital outputs that provide 3.3v to the divider network on a given column. Unaddressed columns should be pulled to ground.
Resistive Sensor Network

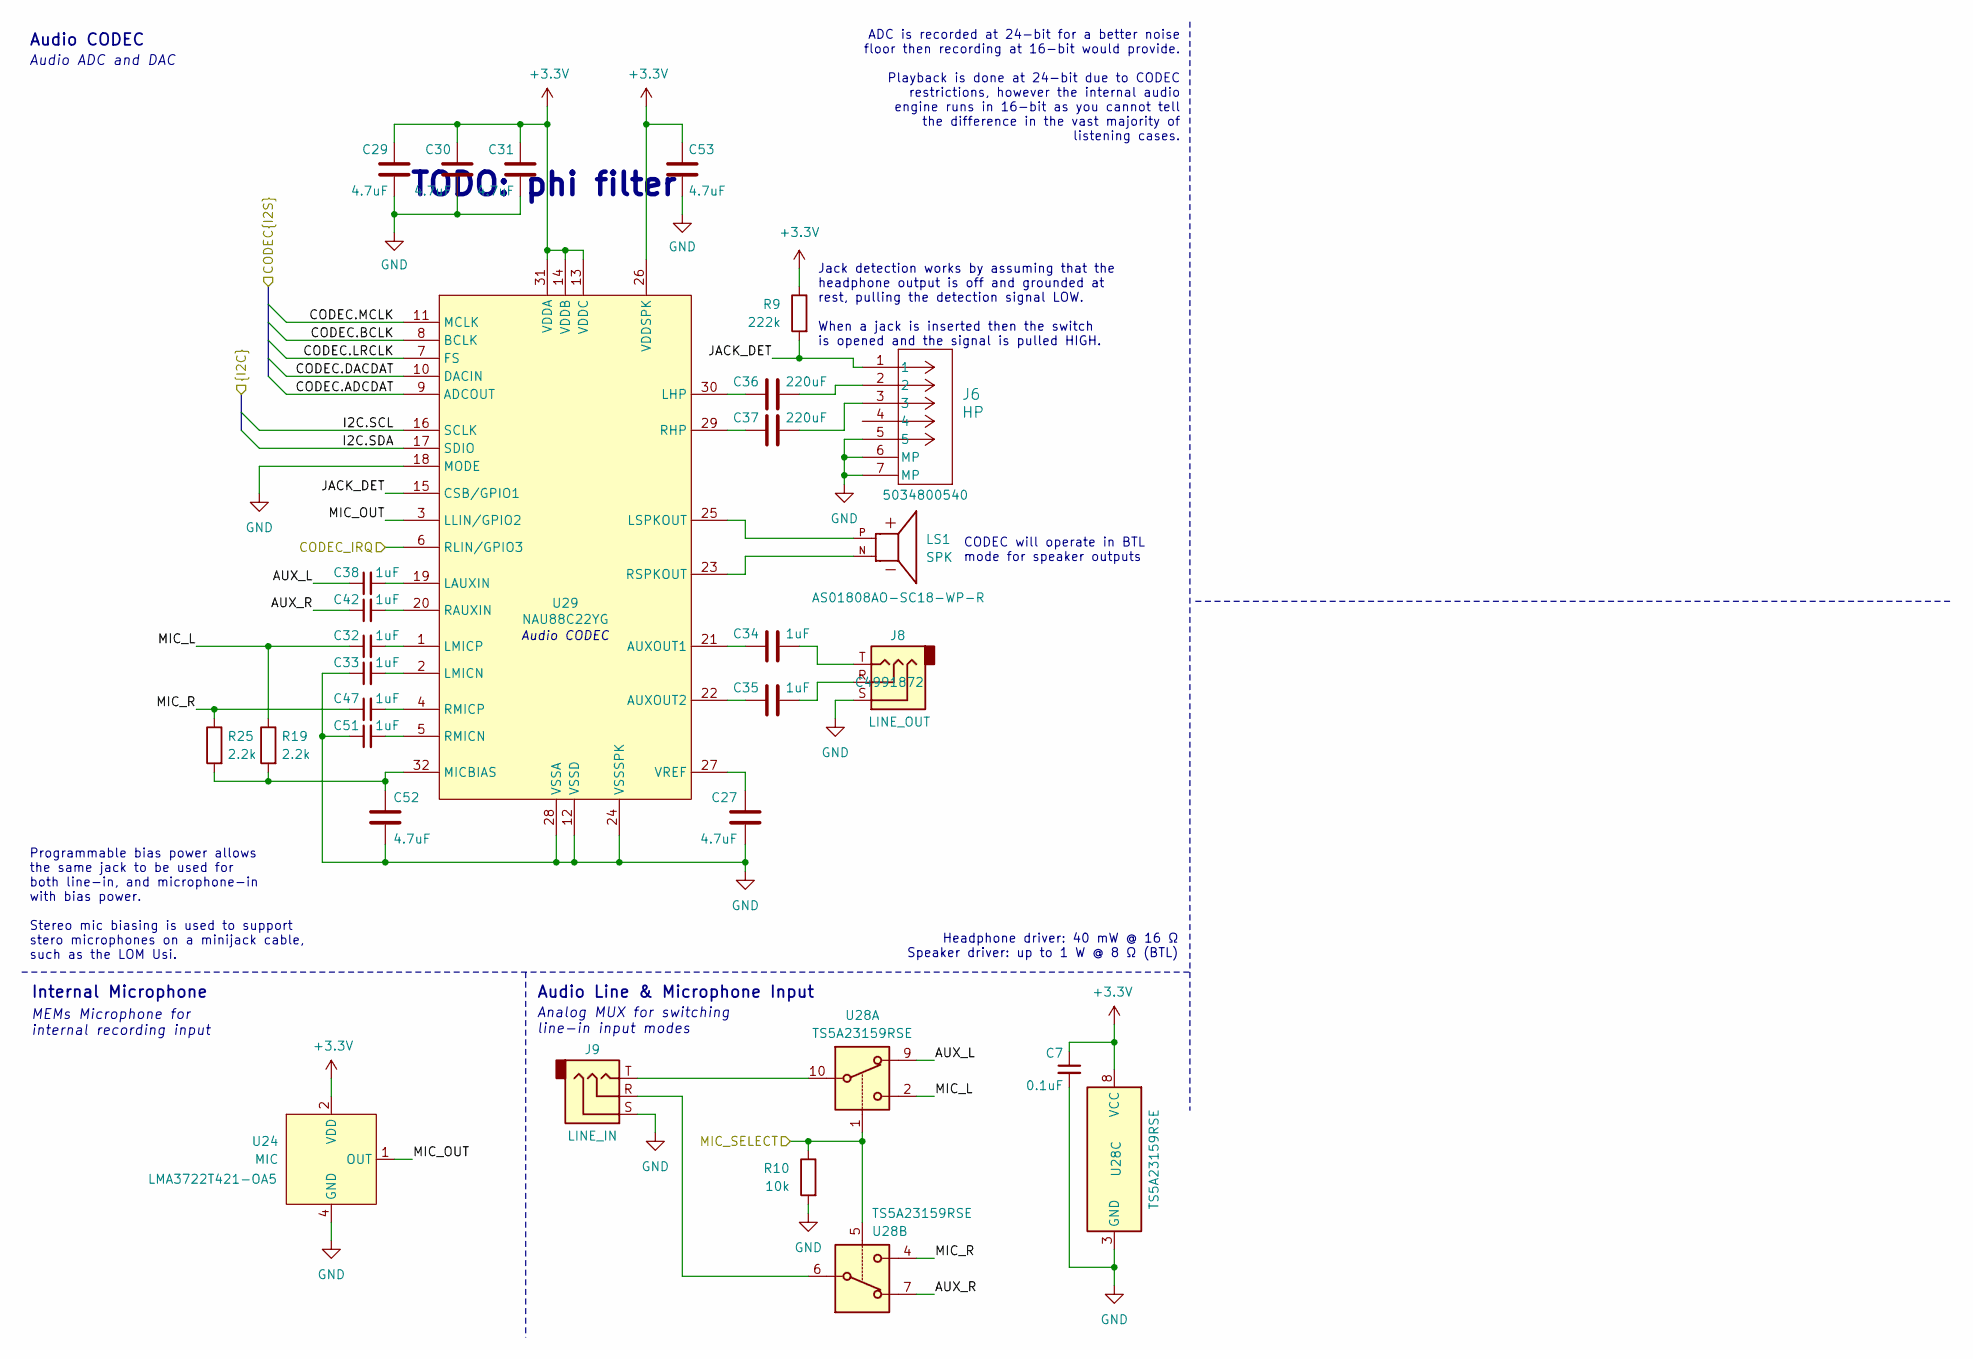
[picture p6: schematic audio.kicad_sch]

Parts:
C7: 0.1uF; C_0201_0603Metric
C27, C29, C30, C31, C52, C53: 4.7uF; C_0201_0603Metric
C32, C33, C34, C35, C38, C42, C47, C51: 1uF; C_0201_0603Metric
C36, C37: 220uF; C_0201_0603Metric
J6: HP; CONN_503480-0540_MOL; JLC C5527934
J8: LINE_OUT; Jack_3.5mm_CUI_SJ-3523-SMT_Horizontal; JLC C4991872
J9: LINE_IN; Jack_3.5mm_CUI_SJ-3523-SMT_Horizontal; JLC C4991872
LS1: SPK; AS01808AO-SC18-WP-R; PARTREV B
R9: 222k; R_0201_0603Metric
R10: 10k; R_0201_0603Metric
R19, R25: 2.2k; R_0201_0603Metric
U24: MIC; LMA3722T421-OA5; JLC C5373233
U28: TS5A23159RSE; Texas_R-PUQFN-N10; JLC C138710
U29: NAU88C22YG; JLC C914209

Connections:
+3.3V: C7.1, C29.1, C30.1, C31.1, C53.1, R9.1, U24.2 (VDD), U28.8 (VCC), U29.13 (VDDC), U29.14 (VDDB), U29.26 (VDDSPK), U29.31 (VDDA); also elsewhere on the board
/Audio/AUX_L: C38.1, U28.9
/Audio/AUX_R: C42.1, U28.7
/Audio/CODEC.ADCDAT: U29.9 (ADCOUT); also elsewhere on the board
/Audio/CODEC.BCLK: U29.8 (BCLK); also elsewhere on the board
/Audio/CODEC.DACDAT: U29.10 (DACIN); also elsewhere on the board
/Audio/CODEC.LRCLK: U29.7 (FS); also elsewhere on the board
/Audio/CODEC.MCLK: U29.11 (MCLK); also elsewhere on the board
/Audio/CODEC_IRQ: U29.6 (RLIN/GPIO3); also elsewhere on the board
/Audio/JACK_DET: J6.1, R9.2, U29.15 (CSB/GPIO1)
/Audio/MIC_L: C32.1, R19.1, U28.2
/Audio/MIC_OUT: U24.1 (OUT), U29.3 (LLIN/GPIO2)
/Audio/MIC_R: C47.1, R25.1, U28.4
/Audio/MIC_SELECT: R10.1, U28.1, U28.5; also elsewhere on the board
/I2C.SCL: U29.16 (SCLK); also elsewhere on the board
/I2C.SDA: U29.17 (SDIO); also elsewhere on the board
GND: C7.2, C27.2, C29.2, C30.2, C31.2, C33.1, C51.1, C52.2, C53.2, J6.5, J6.6 (MP), J6.7 (MP), J8.S, J9.S, R10.2, U24.3 (GND), U24.4 (GND), U28.3 (GND), U29.12 (VSSD), U29.18 (MODE), U29.24 (VSSSPK), U29.28 (VSSA); also elsewhere on the board
unnamed: C34.2, J8.T
unnamed: C35.2, J8.R
unnamed: C36.2, J6.2
unnamed: C37.2, J6.3
unnamed: J9.R, U28.6
unnamed: J9.T, U28.10
unnamed: C34.1, U29.21 (AUXOUT1)
unnamed: C35.1, U29.22 (AUXOUT2)
unnamed: C38.2, U29.19 (LAUXIN)
unnamed: C36.1, U29.30 (LHP)
unnamed: C33.2, U29.2 (LMICN)
unnamed: C32.2, U29.1 (LMICP)
unnamed: LS1.P, U29.25 (LSPKOUT)
unnamed: C52.1, R19.2, R25.2, U29.32 (MICBIAS)
unnamed: C42.2, U29.20 (RAUXIN)
unnamed: C37.1, U29.29 (RHP)
unnamed: C51.2, U29.5 (RMICN)
unnamed: C47.2, U29.4 (RMICP)
unnamed: LS1.N, U29.23 (RSPKOUT)
unnamed: C27.1, U29.27 (VREF)

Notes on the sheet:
MEMs Microphone for internal recording input
Audio CODEC
TODO: phi filter
Jack detection works by assuming that the headphone output is off and grounded at rest, pulling the detection signal LOW. When a jack is inserted then the switch is opened and the signal is pulled HIGH.
Analog MUX for switching line-in input modes
Programmable bias power allows the same jack to be used for both line-in, and microphone-in with bias power. Stereo mic biasing is used to support stero microphones on a minijack cable, such as the LOM Usi.
Audio Line & Microphone Input
CODEC will operate in BTL mode for speaker outputs
Audio ADC and DAC
Headphone driver: 40 mW @ 16 Ω Speaker driver: up to 1 W @ 8 Ω (BTL)
ADC is recorded at 24-bit for a better noise floor then recording at 16-bit would provide. Playback is done at 24-bit due to CODEC restrictions, however the internal audio engine runs in 16-bit as you cannot tell the difference in the vast majority of listening cases.
Internal Microphone

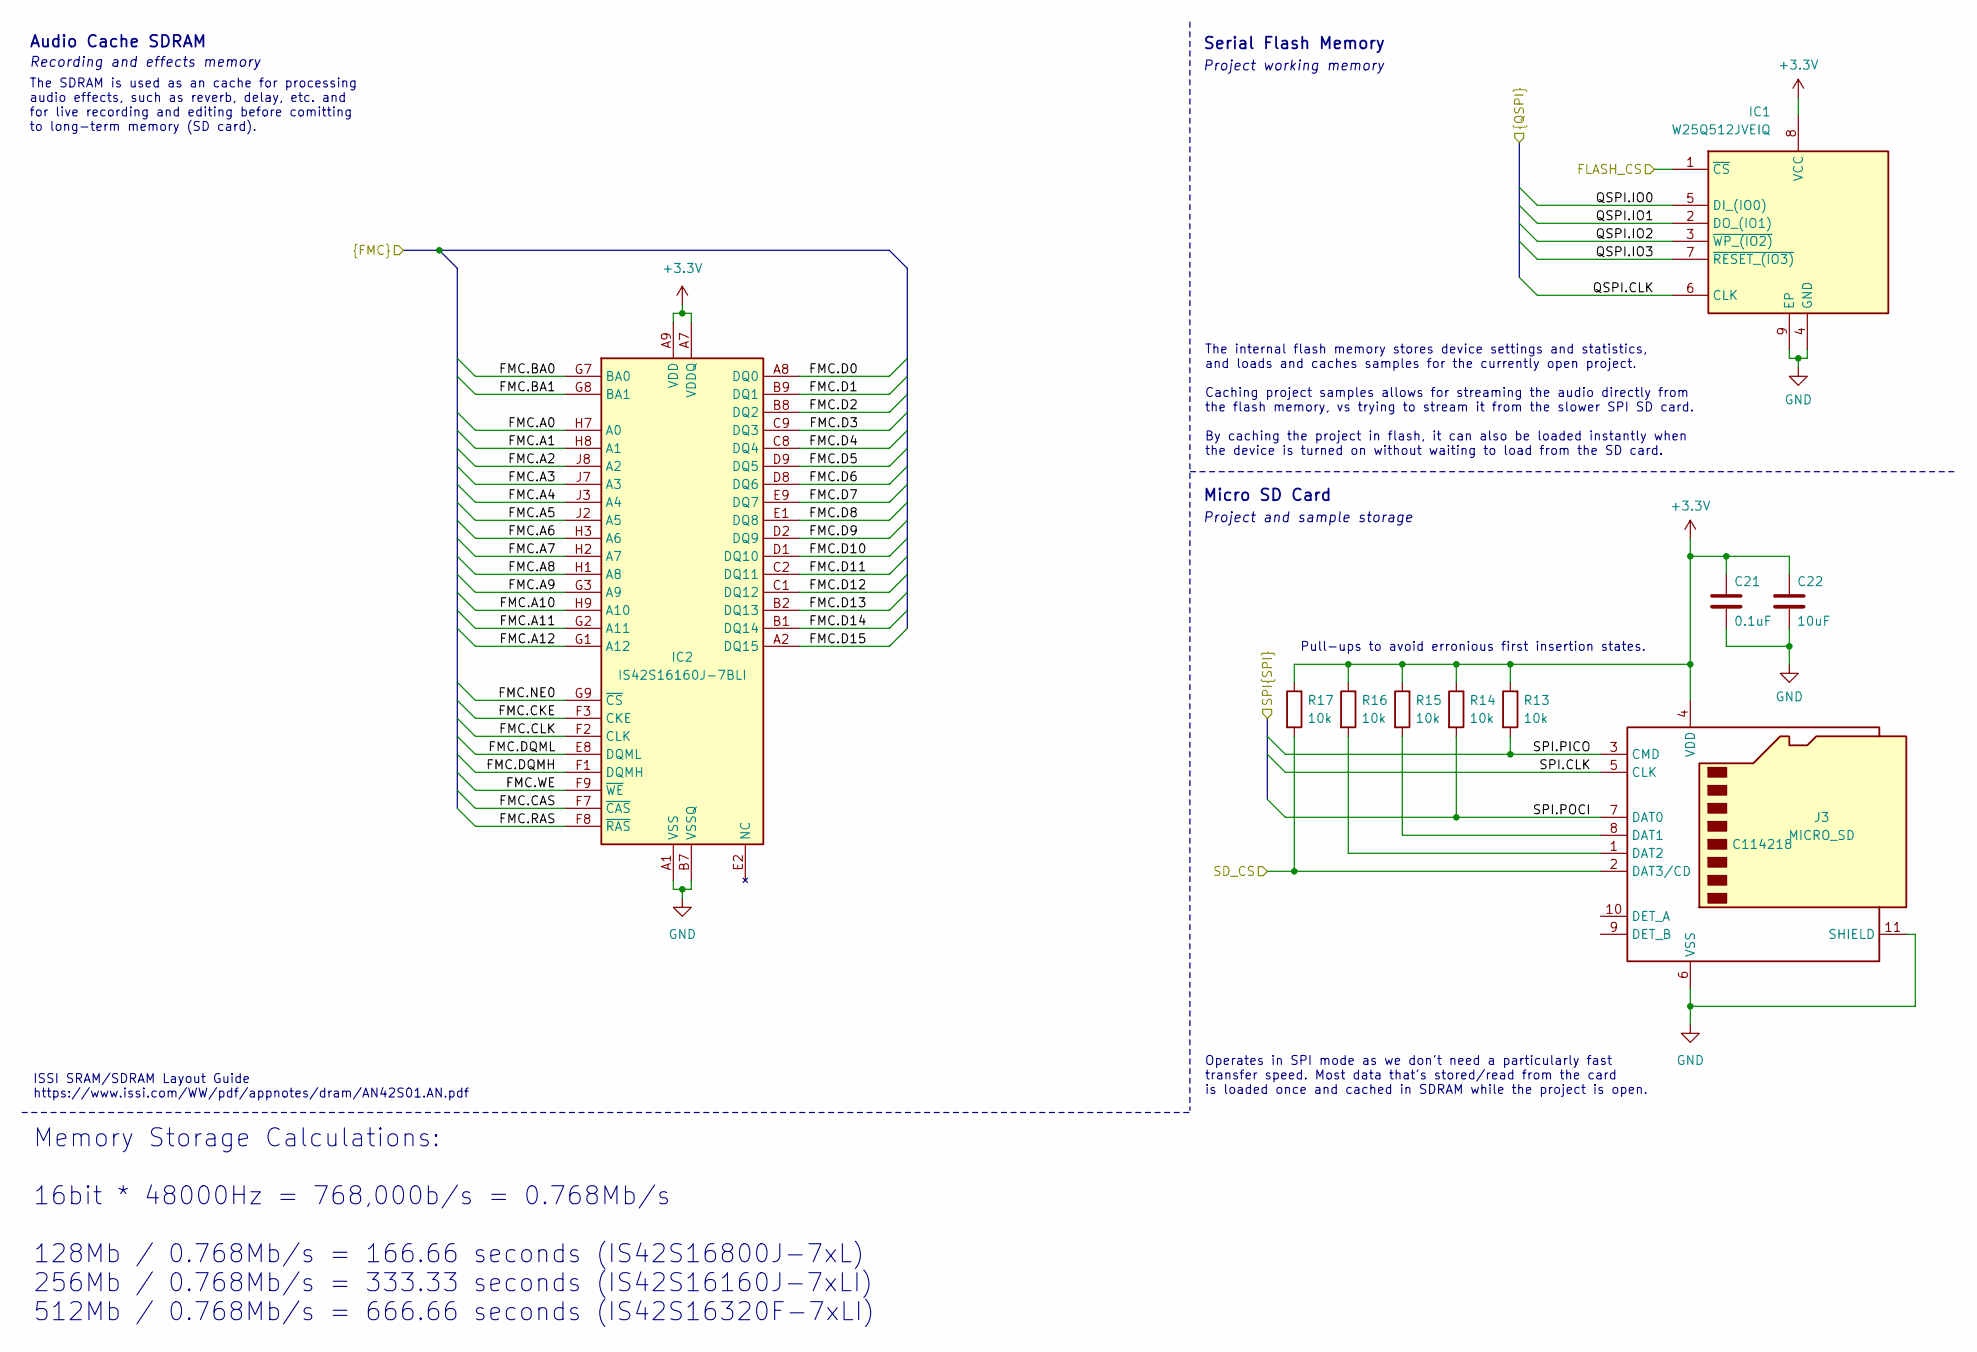
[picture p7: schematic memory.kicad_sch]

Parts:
C21: 0.1uF; C_0402_1005Metric
C22: 10uF; C_0402_1005Metric
IC1: W25Q512JVEIQ; Mouser Part Number 454-W25Q512JVEIQ
IC2: IS42S16160J-7BLI; Mouser Part Number 870-42S16160J7BLI
J3: MICRO_SD; microSD_HC_Hirose_DM3AT-SF-PEJM5; JLC C114218
R13, R14, R15, R16, R17: 10k; R_0402_1005Metric

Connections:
+3.3V: C21.1, C22.1, IC1.8 (VCC), IC2.A7 (VDDQ), IC2.A9 (VDD), IC2.B3 (VDDQ), IC2.C7 (VDDQ), IC2.D3 (VDDQ), IC2.E7 (VDD), IC2.J9 (VDD), J3.4 (VDD), R13.1, R14.1, R15.1, R16.1, R17.1; also elsewhere on the board
/Display/FMC.A0: IC2.H7 (A0); also elsewhere on the board
/Display/FMC.A1: IC2.H8 (A1); also elsewhere on the board
/Display/FMC.A2: IC2.J8 (A2); also elsewhere on the board
/Display/FMC.A3: IC2.J7 (A3); also elsewhere on the board
/Display/FMC.A4: IC2.J3 (A4); also elsewhere on the board
/Display/FMC.A5: IC2.J2 (A5); also elsewhere on the board
/Display/FMC.A6: IC2.H3 (A6); also elsewhere on the board
/Display/FMC.A7: IC2.H2 (A7); also elsewhere on the board
/Display/FMC.A8: IC2.H1 (A8); also elsewhere on the board
/Display/FMC.A9: IC2.G3 (A9); also elsewhere on the board
/Display/FMC.A10: IC2.H9 (A10); also elsewhere on the board
/Display/FMC.A11: IC2.G2 (A11); also elsewhere on the board
/Display/FMC.A12: IC2.G1 (A12); also elsewhere on the board
/Display/FMC.BA0: IC2.G7 (BA0); also elsewhere on the board
/Display/FMC.BA1: IC2.G8 (BA1); also elsewhere on the board
/Display/FMC.CAS: IC2.F7 (~CAS); also elsewhere on the board
/Display/FMC.CKE: IC2.F3 (CKE); also elsewhere on the board
/Display/FMC.CLK: IC2.F2 (CLK); also elsewhere on the board
/Display/FMC.D0: IC2.A8 (DQ0); also elsewhere on the board
/Display/FMC.D1: IC2.B9 (DQ1); also elsewhere on the board
/Display/FMC.D2: IC2.B8 (DQ2); also elsewhere on the board
/Display/FMC.D3: IC2.C9 (DQ3); also elsewhere on the board
/Display/FMC.D4: IC2.C8 (DQ4); also elsewhere on the board
/Display/FMC.D5: IC2.D9 (DQ5); also elsewhere on the board
/Display/FMC.D6: IC2.D8 (DQ6); also elsewhere on the board
/Display/FMC.D7: IC2.E9 (DQ7); also elsewhere on the board
/Display/FMC.D8: IC2.E1 (DQ8); also elsewhere on the board
/Display/FMC.D9: IC2.D2 (DQ9); also elsewhere on the board
/Display/FMC.D10: IC2.D1 (DQ10); also elsewhere on the board
/Display/FMC.D11: IC2.C2 (DQ11); also elsewhere on the board
/Display/FMC.D12: IC2.C1 (DQ12); also elsewhere on the board
/Display/FMC.D13: IC2.B2 (DQ13); also elsewhere on the board
/Display/FMC.D14: IC2.B1 (DQ14); also elsewhere on the board
/Display/FMC.D15: IC2.A2 (DQ15); also elsewhere on the board
/Display/FMC.DQMH: IC2.F1 (DQMH); also elsewhere on the board
/Display/FMC.DQML: IC2.E8 (DQML); also elsewhere on the board
/Display/FMC.NE0: IC2.G9 (~CS); also elsewhere on the board
/Display/FMC.RAS: IC2.F8 (~RAS); also elsewhere on the board
/Display/FMC.WE: IC2.F9 (~WE); also elsewhere on the board
/MCU/FLASH_CS: IC1.1 (~CS); also elsewhere on the board
/MCU/QSPI.CLK: IC1.6 (CLK); also elsewhere on the board
/MCU/QSPI.IO0: IC1.5 (DI_(IO0)); also elsewhere on the board
/MCU/QSPI.IO1: IC1.2 (DO_(IO1)); also elsewhere on the board
/MCU/QSPI.IO2: IC1.3 (~WP_(IO2)); also elsewhere on the board
/MCU/QSPI.IO3: IC1.7 (~RESET_(IO3)); also elsewhere on the board
/MCU/SPI.CLK: J3.5 (CLK); also elsewhere on the board
/MCU/SPI.PICO: J3.3 (CMD), R13.2; also elsewhere on the board
/MCU/SPI.POCI: J3.7 (DAT0), R14.2; also elsewhere on the board
/Memory/SD_CS: J3.2 (DAT3/CD), R17.2
GND: C21.2, C22.2, IC1.4 (GND), IC1.9 (EP), IC2.A1 (VSS), IC2.A3 (VSSQ), IC2.B7 (VSSQ), IC2.C3 (VSSQ), IC2.D7 (VSSQ), IC2.E3 (VSS), IC2.J1 (VSS), J3.6 (VSS), J3.11 (SHIELD); also elsewhere on the board
unnamed: J3.8 (DAT1), R15.2
unnamed: J3.1 (DAT2), R16.2

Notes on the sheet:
The internal flash memory stores device settings and statistics, and loads and caches samples for the currently open project. Caching project samples allows for streaming the audio directly from the flash memory, vs trying to stream it from the slower SPI SD card. By caching the project in flash, i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
The SDRAM is used as an cache for processing audio effects, such as reverb, delay, etc. and for live recording and editing before comitting to long-term memory (SD card).
ISSI SRAM/SDRAM Layout Guide https://www.issi.com/WW/pdf/appnotes/dram/AN42S01.AN.pdf
Audio Cache SDRAM
Operates in SPI mode as we don't need a particularly fast transfer speed. Most data that's stored/read from the card is loaded once and cached in SDRAM while the project is open.
Recording and effects memory
Micro SD Card
Project working memory
Serial Flash Memory
Pull-ups to avoid erronious first insertion states.
Project and sample storage
Memory Storage Calculations: 16bit * 48000Hz = 768,000b/s = 0.768Mb/s 128Mb / 0.768Mb/s = 166.66 seconds (IS42S16800J-7xL) 256Mb / 0.768Mb/s = 333.33 seconds (IS42S16160J-7xLI) 512Mb / 0.768Mb/s = 666.66 seconds (IS42S16320F-7xLI)

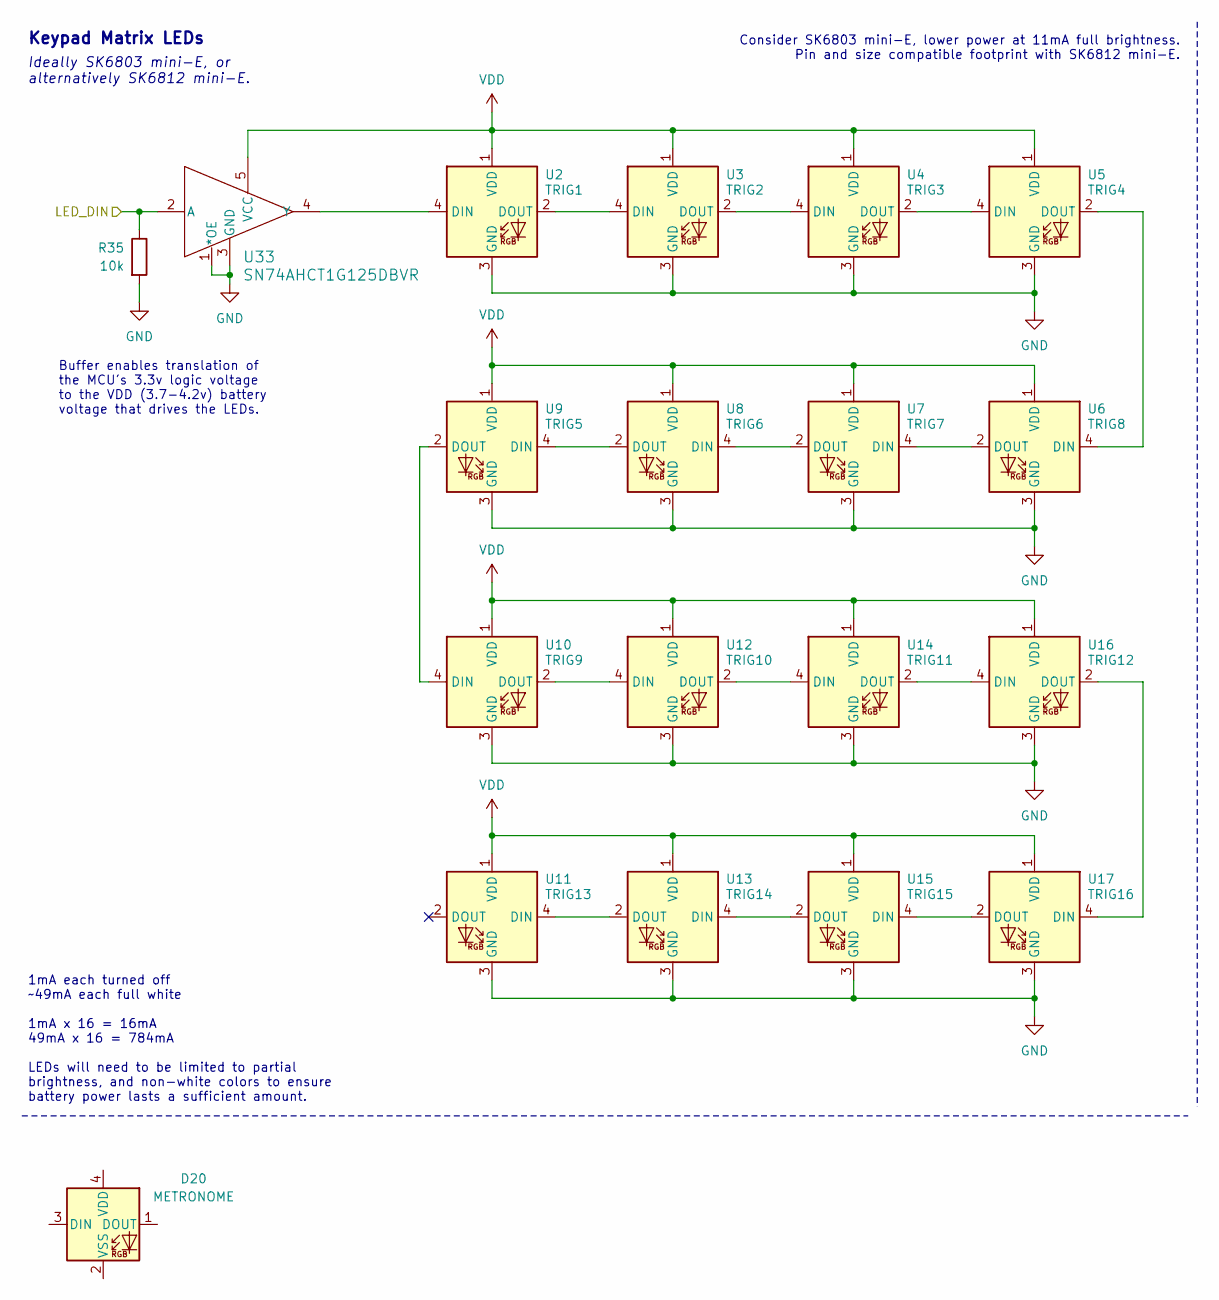
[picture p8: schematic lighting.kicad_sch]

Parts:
D20: METRONOME; LED_SK6812MINI_PLCC4_3.5x3.5mm_P1.75mm
R35: 10k; R_0402_1005Metric
U2: TRIG1; SK6812MINI-E; JLC C5149201
U3: TRIG2; SK6812MINI-E; JLC C5149201
U4: TRIG3; SK6812MINI-E; JLC C5149201
U5: TRIG4; SK6812MINI-E; JLC C5149201
U6: TRIG8; SK6812MINI-E; JLC C5149201
U7: TRIG7; SK6812MINI-E; JLC C5149201
U8: TRIG6; SK6812MINI-E; JLC C5149201
U9: TRIG5; SK6812MINI-E; JLC C5149201
U10: TRIG9; SK6812MINI-E; JLC C5149201
U11: TRIG13; SK6812MINI-E; JLC C5149201
U12: TRIG10; SK6812MINI-E; JLC C5149201
U13: TRIG14; SK6812MINI-E; JLC C5149201
U14: TRIG11; SK6812MINI-E; JLC C5149201
U15: TRIG15; SK6812MINI-E; JLC C5149201
U16: TRIG12; SK6812MINI-E; JLC C5149201
U17: TRIG16; SK6812MINI-E; JLC C5149201
U33: SN74AHCT1G125DBVR; JLC C7484

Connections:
+BATT: U2.1 (VDD), U3.1 (VDD), U4.1 (VDD), U5.1 (VDD), U6.1 (VDD), U7.1 (VDD), U8.1 (VDD), U9.1 (VDD), U10.1 (VDD), U11.1 (VDD), U12.1 (VDD), U13.1 (VDD), U14.1 (VDD), U15.1 (VDD), U16.1 (VDD), U17.1 (VDD), U33.5 (VCC); also elsewhere on the board
/Lighting/LED_DIN: R35.1, U33.2 (A)
GND: R35.2, U2.3 (GND), U3.3 (GND), U4.3 (GND), U5.3 (GND), U6.3 (GND), U7.3 (GND), U8.3 (GND), U9.3 (GND), U10.3 (GND), U11.3 (GND), U12.3 (GND), U13.3 (GND), U14.3 (GND), U15.3 (GND), U16.3 (GND), U17.3 (GND), U33.1 (*OE), U33.3 (GND); also elsewhere on the board
unnamed: U2.4 (DIN), U33.4 (Y)
unnamed: U2.2 (DOUT), U3.4 (DIN)
unnamed: U3.2 (DOUT), U4.4 (DIN)
unnamed: U4.2 (DOUT), U5.4 (DIN)
unnamed: U5.2 (DOUT), U6.4 (DIN)
unnamed: U6.2 (DOUT), U7.4 (DIN)
unnamed: U7.2 (DOUT), U8.4 (DIN)
unnamed: U8.2 (DOUT), U9.4 (DIN)
unnamed: U9.2 (DOUT), U10.4 (DIN)
unnamed: U10.2 (DOUT), U12.4 (DIN)
unnamed: U11.4 (DIN), U13.2 (DOUT)
unnamed: U12.2 (DOUT), U14.4 (DIN)
unnamed: U13.4 (DIN), U15.2 (DOUT)
unnamed: U14.2 (DOUT), U16.4 (DIN)
unnamed: U15.4 (DIN), U17.2 (DOUT)
unnamed: U16.2 (DOUT), U17.4 (DIN)

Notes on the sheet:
1mA each turned off ~49mA each full white 1mA x 16 = 16mA 49mA x 16 = 784mA LEDs will need to be limited to partial brightness, and non-white colors to ensure battery power lasts a sufficient amount.
Ideally SK6803 mini-E, or alternatively SK6812 mini-E.
Keypad Matrix LEDs
Buffer enables translation of the MCU's 3.3v logic voltage to the VDD (3.7-4.2v) battery voltage that drives the LEDs.
Consider SK6803 mini-E, lower power at 11mA full brightness. Pin and size compatible footprint with SK6812 mini-E.

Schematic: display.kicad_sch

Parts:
C8, C24: 0.1uF; C_0402_1005Metric
C25: 10uF; C_0402_1005Metric
JP1: MODE0; SolderJumper-3_P1.3mm_Bridged12_RoundedPad1.0x1.5mm
JP2: MODE1; SolderJumper-3_P1.3mm_Bridged12_RoundedPad1.0x1.5mm
JP3: MODE2; SolderJumper-3_P1.3mm_Bridged12_RoundedPad1.0x1.5mm
JP4: MODE3; SolderJumper-3_P1.3mm_Bridged12_RoundedPad1.0x1.5mm
R4, R5, R6, R7: 6R; R_0402_1005Metric
R11: 10k; R_0402_1005Metric
U19: ER-TFT024IPS-3

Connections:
+3.3V: C8.1, C24.1, C25.1, JP1.1 (A), JP2.3 (B), JP3.3 (B), JP4.3 (B), U19.1 (A), U19.40 (VDDI), U19.41 (VDDI), U19.42 (VCI); also elsewhere on the board
/Display/DISPLAY_TE: U19.39 (TE)
/Display/FMC.A0: U19.37 (DCx); also elsewhere on the board
/Display/FMC.D0: U19.32 (D0); also elsewhere on the board
/Display/FMC.D1: U19.31 (D1); also elsewhere on the board
/Display/FMC.D2: U19.30 (D2); also elsewhere on the board
/Display/FMC.D3: U19.29 (D3); also elsewhere on the board
/Display/FMC.D4: U19.28 (D4); also elsewhere on the board
/Display/FMC.D5: U19.27 (D5); also elsewhere on the board
/Display/FMC.D6: U19.26 (D6); also elsewhere on the board
/Display/FMC.D7: U19.25 (D7); also elsewhere on the board
/Display/FMC.D8: U19.24 (D8); also elsewhere on the board
/Display/FMC.D9: U19.23 (D9); also elsewhere on the board
/Display/FMC.D10: U19.22 (D10); also elsewhere on the board
/Display/FMC.D11: U19.21 (D11); also elsewhere on the board
/Display/FMC.D12: U19.20 (D12); also elsewhere on the board
/Display/FMC.D13: U19.19 (D13); also elsewhere on the board
/Display/FMC.D14: U19.18 (D14); also elsewhere on the board
/Display/FMC.D15: U19.17 (D15); also elsewhere on the board
/Display/FMC.NE1: U19.38 (CSx); also elsewhere on the board
/Display/FMC.NOE: U19.35 (RDx); also elsewhere on the board
/Display/FMC.NWE: U19.36 (WRx); also elsewhere on the board
/Display/MODE0: JP1.2 (C), U19.6 (MODE0)
/Display/MODE1: JP2.2 (C), U19.7 (MODE1)
/Display/MODE2: JP3.2 (C), U19.8 (MODE2)
/Display/MODE3: JP4.2 (C), U19.9 (MODE3)
/Display/TOUCH_INT: U19.46 (INT); also elsewhere on the board
/Display/TOUCH_RST: R11.1, U19.47 (RESET); also elsewhere on the board
/I2C.SCL: U19.44 (SCL); also elsewhere on the board
/I2C.SDA: U19.45 (SDA); also elsewhere on the board
GND: C8.2, C24.2, C25.2, JP1.3 (B), JP2.1 (A), JP3.1 (A), JP4.1 (A), R4.1, R5.1, R6.1, R7.1, R11.2, U19.11 (VSYNC), U19.12 (HSYNC), U19.13 (DOTCLK), U19.14 (DE), U19.15 (D17), U19.16 (D16), U19.43 (GND), U19.48 (GND), U19.49 (GND), U19.50 (GND); also elsewhere on the board
unnamed: R4.2, U19.2 (K1)
unnamed: R5.2, U19.3 (K2)
unnamed: R6.2, U19.4 (K3)
unnamed: R7.2, U19.5 (K4)

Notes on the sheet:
Pull touch reset signal low to keep the touch driver in reset until the MCU pulls it high
Mode jumpers default to 16-bit 8080 parallel interface

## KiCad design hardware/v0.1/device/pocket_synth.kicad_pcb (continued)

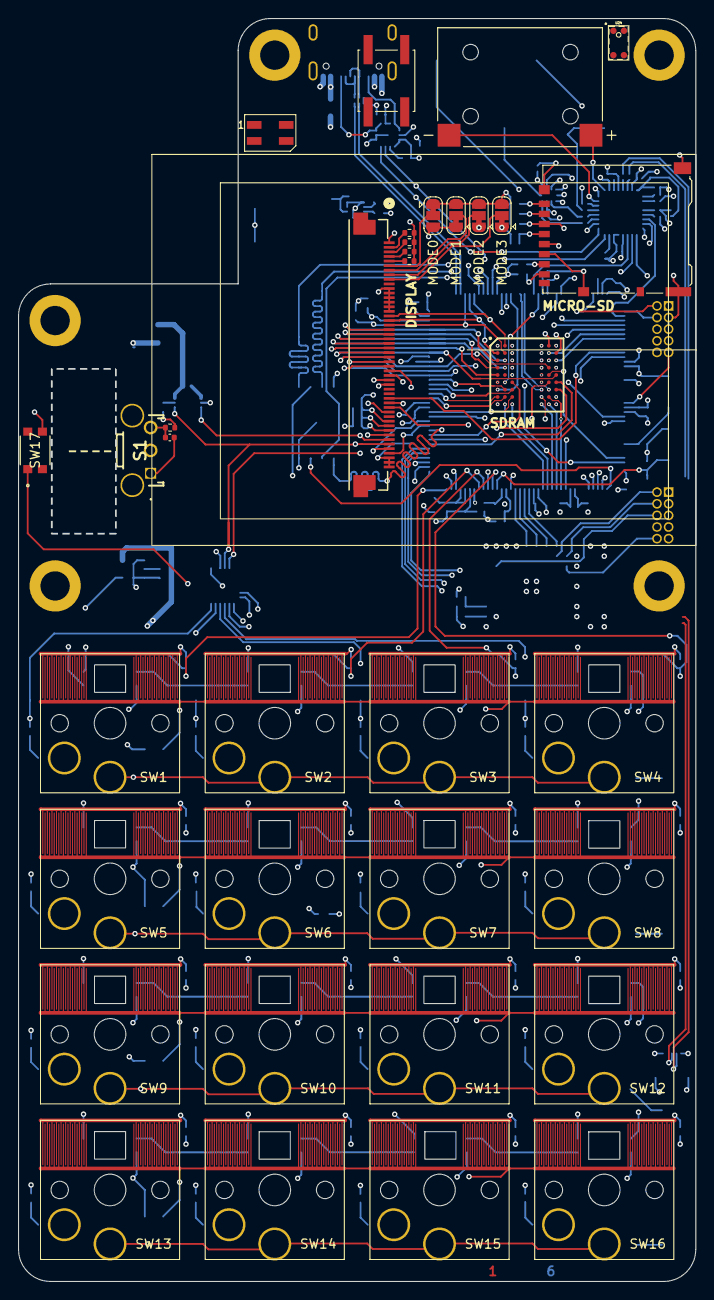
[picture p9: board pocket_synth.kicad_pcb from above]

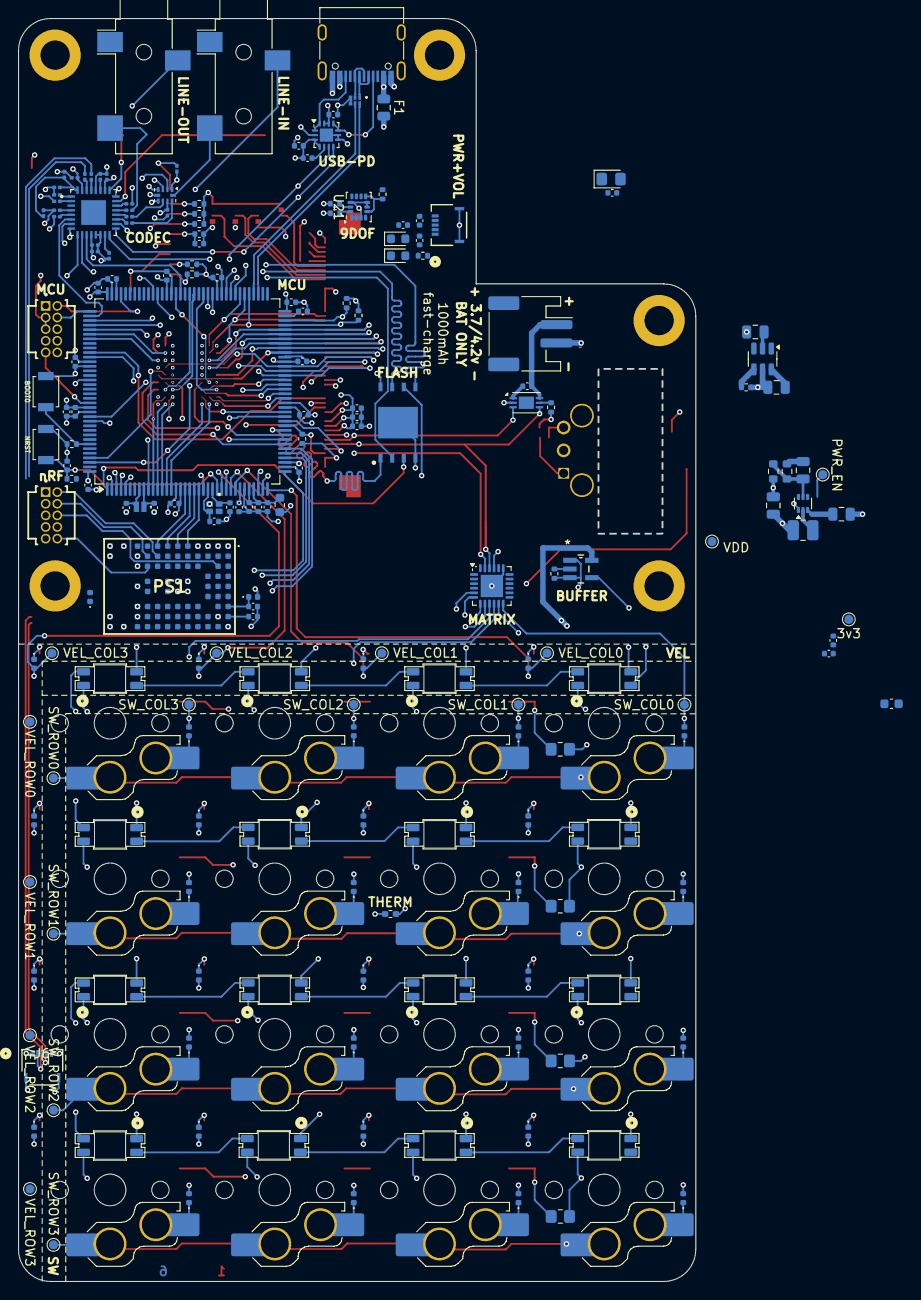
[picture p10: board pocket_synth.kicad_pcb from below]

Board: 6 copper layers, 74.0 x 138.0 mm, 231 parts (175 on the bottom side), 221 nets.

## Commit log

2025-08-08 feat: various layout adjustments
    [keypad.kicad_sch, pocket_synth.kicad_pcb, power.kicad_sch]
2025-08-08 feat: project organization, add knob, pcb layout, and 3d models
    [audio.kicad_sch, keypad.kicad_sch, knob.kicad_pcb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]
2025-08-08 feat: various scroll wheel layout changes
    [keypad.kicad_sch, pocket_synth.kicad_pcb]
2025-08-09 feat: add various connectors
    [pocket_synth.kicad_pcb, power.kicad_sch]
2025-08-09 feat: various footprint updates, 3d models, tollerances
    [memory.kicad_sch, pocket_synth.kicad_pcb, pocket_synth.kicad_sch]
2025-08-09 feat: audio schematic, FMC bus, SDRAM connections
    [MCU.kicad_sch, audio.kicad_sch, display.kicad_sch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]
2025-08-09 feat: start codec layout
    [MCU.kicad_sch, audio.kicad_sch, display.kicad_sch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]
2025-08-10 feat: various layouts, changed SDRAM to BGA
    [MCU.kicad_sch, audio.kicad_sch, keypad.kicad_sch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]
2025-08-10 feat: BGA routing for SDRAM
    [MCU.kicad_sch, memory.kicad_sch, pocket_synth.kicad_pcb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]
2025-08-10 feat: more SDRAM routing
    [pocket_synth.kicad_pcb]
2025-08-10 feat: display FPC routing
    [MCU.kicad_sch, pocket_synth.kicad_pcb]
2025-08-11 feat: various audio and power schematic layout
    [MCU.kicad_sch, audio.kicad_sch, display.kicad_sch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]
2025-08-11 feat: speaker amplifier setup
    [MCU.kicad_sch, audio.kicad_sch, pocket_synth.kicad_pcb]
2025-08-11 feat: audio system layout
    [audio.kicad_sch, pocket_synth.kicad_pcb]
2025-08-12 feat: change codec to NAU88C22YG
    [MCU.kicad_sch, audio.kicad_sch, pocket_synth.kicad_pcb]
2025-08-12 feat: add speaker
    [audio.kicad_sch, pocket_synth.kicad_pcb]
2025-08-12 feat: add speaker model to symbol
    [audio.kicad_sch]
2025-08-12 feat: add MEMs microphone
    [audio.kicad_sch, pocket_synth.kicad_pcb]
2025-08-13 feat: various PCB layout and routing
    [MCU.kicad_sch, audio.kicad_sch, keypad.kicad_sch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]
2025-08-13 chore: display FPC layout
    [pocket_synth.kicad_pcb]
2025-08-13 chore: shift STM32 closer to FPC
    [pocket_synth.kicad_pcb]
2025-08-13 feat: add BMPU debug connector
    [MCU.kicad_sch, pocket_synth.kicad_pcb]
2025-08-13 feat: add micro SD slot model
    [MCU.kicad_sch, pocket_synth.kicad_pcb]
2025-08-13 feat: fit SD card and SPI bus to layout
    [MCU.kicad_sch, memory.kicad_sch, pocket_synth.kicad_pcb]
2025-08-13 chore: audio routing and UART port mapping
    [MCU.kicad_sch, audio.kicad_sch, pocket_synth.kicad_pcb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]
2025-08-14 fix: disconnected net buses
    [MCU.kicad_sch, audio.kicad_sch, pocket_synth.kicad_pcb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]
2025-08-15 feat: add audio routing muxes
    [audio.kicad_sch, keypad.kicad_sch, pocket_synth.kicad_pcb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]
2025-08-16 feat: various layout, start adding capacitive pads
    [MCU.kicad_sch, audio.kicad_sch, keypad.kicad_sch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]
2025-08-16 feat: add integrated flash memory
    [MCU.kicad_sch, keypad.kicad_sch, memory.kicad_sch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]
2025-08-17 feat: add ESD filter
    [MCU.kicad_sch, pocket_synth.kicad_pcb, power.kicad_sch]
2025-08-17 feat: route NOR flash
    [pocket_synth.kicad_pcb]
2025-08-19 feat: start adding velocity button circuit
    [keypad.kicad_sch]
2025-08-19 feat: resistor divider matrix for resistive touch
    [keypad.kicad_sch]
2025-08-20 feat: keypad schematic organization
    [keypad.kicad_sch]
2025-08-20 feat: update board layout to include velocity matrix
    [keypad.kicad_sch, pocket_synth.kicad_pcb]
2025-08-20 feat: add anti-ghosting resistors to resistive matrix
    [keypad.kicad_sch, pocket_synth.kicad_pcb]
2025-08-21 feat: keypad schematic cleanup
    [MCU.kicad_sch, keypad.kicad_sch, pocket_synth.kicad_sch]
2025-08-21 feat: power schematic cleanup, add USB PD controller
    [power.kicad_sch]
2025-08-21 feat: start adding battery fuel gauge
    [memory.kicad_sch, power.kicad_sch]
2025-08-21 feat: add buffer for LED logic level conversion
    [keypad.kicad_sch, lighting.kicad_sch]
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2025-08-23 feat: add plated mounting holes
    [audio.kicad_sch, keypad.kicad_sch, memory.kicad_sch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]
2025-08-23 fix: switch resistive pads not connected
2025-08-23 feat: start routing keyswitch pads
    [MCU.kicad_sch, audio.kicad_sch, keypad.kicad_sch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]
2025-08-27 fix: add reset MCU alternate function labels
    [MCU.kicad_sch, pocket_synth.kicad_pcb]
2025-08-27 feat: audio system routing
    [MCU.kicad_sch, audio.kicad_sch, pocket_synth.kicad_pcb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]
2025-08-28 feat: keypad routing and layout
    [keypad.kicad_sch, pocket_synth.kicad_pcb]
2025-08-31 feat: various routing, footprint and schematic cleanup
    [MCU.kicad_sch, audio.kicad_sch, display.kicad_sch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]
2025-09-01 feat: fix incorrect HSE crystal
    [MCU.kicad_sch]
2025-09-01 feat: start replacing expansion port with bluetooth module
    [audio.kicad_sch, memory.kicad_sch, pocket_synth.kicad_pcb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]
2025-09-01 feat: clean up footprints, route bluetooth module
    [pocket_synth.kicad_pcb, rf.kicad_sch]
2025-09-01 feat: add SWD connector, route bluetooth, route velocity matrix
    [MCU.kicad_sch, keypad.kicad_sch, pocket_synth.kicad_pcb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]
2025-09-01 feat: start adding headphone jack connector
    [audio.kicad_sch, pocket_synth.kicad_pcb]
2025-09-01 feat: start JLC DRC validation
    [pocket_synth.kicad_pcb]
2025-09-03 feat: various layout and routing
    [pocket_synth.kicad_pcb]
2025-09-03 chore: move hardware files into versioned directory
    [MCU.kicad_sch, audio.kicad_sch, display.kicad_sch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]
